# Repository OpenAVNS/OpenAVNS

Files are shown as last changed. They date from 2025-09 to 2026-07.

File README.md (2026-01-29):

# OpenAVNS

## Purpose
To develop an open-source, open-architecture auricular vagus nerve stimulator under a distributed development model.
 
Auricular vagus nerve stimulation (aVNS) is a method of neuromodulation that uses electrical pulses applied to nerves near the ear to create a vagus nerve response. This response can lead to reduced sympathetic (fight or flight) and increased parasympathetic (relaxation / everything ok) tone. Adjusting vagal tone using aVNS has been explored by clinical researchers for a number of potential therapeutic applications, including for depression [1], opioid withdraws [2], chronic pain [3], and gastrointestinal issues [4]. In addition, aVNS has been explored in wellness for applications such as stress reduction [5]. We believe an open-source, open-architecture aVNS system would be helpful for users, students, medical researchers, and community members around the world to explore aVNS and to learn more about developing neuromodulation devices under an open source model.
 
1. [Tan, Chaoren et. al. 2023](https://pubmed.ncbi.nlm.nih.gov/37230264/)  
2. [Tirado, Carlos F. et. al. 2022](https://pmc.ncbi.nlm.nih.gov/articles/PMC9385243/)  
3. [Duff, Irina T. et. al. 2024](https://pmc.ncbi.nlm.nih.gov/articles/PMC11543973/)  
4. [Veldman, Fleur et. al. 2025](https://pmc.ncbi.nlm.nih.gov/articles/PMC11769675/)  
5. [Sanches-Perez, Jesus et. al. 2023](https://pmc.ncbi.nlm.nih.gov/articles/PMC10512834/)  

## Principles of OpenAVNS
* _Openness_ – all source files, including code, PCB source files, CAD, and any documentation, available under permissive license
* _Accessibility_ – device developed using freely available tools (KiCad for PCBs, FreeCAD for enclosure, etc.); enclosure able to be 3D printed on home printer; PCBs use only common, off the shelf components and able to be taped out and assembled by a low-cost manufacturer; clear instructions are developed for building, flashing, and testing a device; low-cost, replaceable, commercially available electrodes are used to apply stimulation; apps should be developed on a platform that allows iOS and Android releases simultaneously
* _Wearability_ – device should be as small and unobtrusive as possible while maintaining openness and accessibility. Ideally, all electronics would fit behind the ear (similar to a behind-ear hearing aid or cochlear implant electronics) and can be comfortably worn for at least 30 minutes at a time
* _Effectiveness_ – the device should be capable of outputting stimulation with the same parameters as those used in clinical trials for at least 30 minutes. We note that OpenAVNS cannot be considered to be “effective” for any indication until it has been tested in a clinical trial.
* _Safety_ – the device’s electronics, firmware, software, and mechanical design should all be constructed with user safety in mind, and should be built to the standards of a medical device. We note that until OpenAVNS has been tested and cleared by a regulatory body for human use it cannot be considered “safe”; any use of the source files and documentation in the project must be done for educational purposes only and is done entirely at the user’s own risk. PLEASE DO NOT HURT YOURSELF!
 
## Proposed user needs and design inputs
| User Need | Design Input |
|---|---|
| The device shall apply neuromodulation to the auricular vagus branches at the tragus and cymba concha | Device shall provide two independent biphasic current-controlled stimulation outputs |
| The user shall easily activate, modify, and deactivate stimulation on the device | App shall allow adjustment of stimulation parameters (frequency, pulse width, amplitude) within specified ranges. <br><br> App shall allow initiating and stopping stimulation <br><br> Physical button on device to deactivate stimulation if needed <br><br> App shall be intuitive and easy to use |
| The user shall comfortably wear the device | Weight less than 40g <br><br> Device fits behind ear <br><br> Remains securely in place for 30 minutes of typical non-athletic activity without discomfort |
| The user shall apply neuromodulation typical of clinical studies reported in literature | Adjustable outputs between 1-50Hz, 100-500us pulse width, 0-2mA amplitude <br><br> Capable of outputting at maximum settings on one channel for a minimum of 30min |
| The device is open and accessible to a large range of users in different situations | Rechargeable by USB-C <br><br> Uses commercial off the shelf replaceable electrodes <br><br> App available on iOS and Android platforms |
| The device is safe to use | Device hardware prevents DC charge or amplitudes outside of the operating parameters from presenting at the electrode sites <br><br> Physical button on device to stop stimulation <br><br> Impedance measurement on output used to stop stimulation if electrodes are disconnected (short or open circuit) <br><br> Stimulation stops if wireless connection to app is interrupted <br><br> Firmware automatically stops stimulation after 30min regardless of other factors |

## Project Goals / Timeline
_2025_
* _August:_ set up project structure, onboard contributors, assign tasks, generate block diagrams of system
* _September:_ design and tape out first version of PCB, develop test firmware, generate proof of concept drawings / mock-ups for enclosure and user interface
* _October:_ test and document initial PCB and firmware for power draw, output integrity, and safety, develop initial app prototype, combine board needs and enclosure drawings to create CAD model
* _November:_ tape out second version of PCB designed for enclosure, conduct fit test, create alpha version of iOS and Android app
* _December:_ first system tests of prototype device (HW + FW + Enclosure + App)

## Contributors
Last updated 10/31/2025
* [Alex Baldwin](https://www.linkedin.com/in/alexbbaldwin/) - Founder, PCB schematics and layout
* [Amanda Cheung](https://www.linkedin.com/in/amandacheung8/) - Enclosure CAD
* [Maro Michailidou](https://www.linkedin.com/in/maro-michailidou/) - PCB Layout Review

## Disclaimer
The contents of this document, the OpenAVNS repository on GitHub, and any other documents or communication released by the OpenAVNS project (the “Materials”) are subject to revision. No representation or warranty, express or implied, is provided in relation to the accuracy, correctness, completeness, or reliability of the information, opinions, or conclusions expressed in this repository.

The Materials are experimental in nature and should be used with prudence and appropriate caution. Any use is voluntary and at your own risk.

The Materials are made available “as is” by the contributors to this repository (collectively, “Providers”). Providers expressly disclaim all warranties, express or implied, arising in connection with the Materials, or arising out of a course of performance, dealing, or trade usage, including, without limitation, any warranties of title, noninfringement, merchantability, or fitness for a particular purpose.

Any user of the Materials agrees to forever indemnify, defend, and hold harmless Providers from and against, and to waive any and all claims against Providers for any and all claims, suits, demands, liability, loss or damage whatsoever, including attorneys' fees, whether direct or consequential, on account of any loss, injury, death or damage to any person or (including without limitation all agents and employees of Providers and all property owned by, leased to or used by either Providers) or on account of any loss or damages to business or reputations or privacy of any persons, arising in whole or in part in any way from use of the Materials or in any way connected therewith or in any way related thereto.

The Materials, any related materials, and all intellectual property therein, are owned by Providers.

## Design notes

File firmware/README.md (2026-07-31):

# OpenAVNS Bring-Up Shell

Interactive shell firmware for board bring-up and testing of the OpenAVNS nRF52840 PCBA. Runs on Zephyr RTOS (via the nRF Connect SDK) and provides a command-line interface over **J-Link RTT** or **USB-C serial** for toggling GPIOs, scanning I2C buses, driving the stim outputs, and testing the BLE antenna — no code changes needed to test the board.

## Prerequisites

- [nRF Connect SDK (NCS) toolchain](https://developer.nordicsemi.com/nRF_Connect_SDK/doc/latest/nrf/installation.html) — provides `west`, the Zephyr SDK (`arm-zephyr-eabi-gcc`), and CMake/Ninja
- J-Link Software Pack installed (`JLinkExe`, `JLinkRTTClient`) — needed for SWD flashing and the RTT shell backend
- A J-Link probe (e.g. J-Link EDU Mini) wired to the board's SWD header (SWDIO, SWDCLK, GND, VTref)

## Getting the SDK

This firmware is a standalone Zephyr application — the nRF Connect SDK itself (several GB) is **not** vendored in this repo. `firmware/west.yml` is a [west manifest](https://developer.nordicsemi.com/nRF_Connect_SDK/doc/latest/zephyr/guides/west/index.html) that lets you bootstrap a matching SDK workspace from scratch:

```bash
west init -m https://github.com/<org>/OpenAVNS --mf firmware/west.yml --mr main workspace
cd workspace
west update
```

This pulls the exact NCS/Zephyr/nrfxlib revisions this firmware was last built and tested against (pinned in `west.yml`). It's a development snapshot rather than a numbered NCS release — see the comments at the top of `west.yml` if you'd rather move to a stable release tag.

After `west update`, the repo itself is checked out at `workspace/openavns/`, so this application lives at `workspace/openavns/firmware`.

**Already have an NCS workspace set up?** You don't need the `west init` step — just copy or symlink this `firmware/` directory in as an application alongside your existing `zephyr`/`nrf` checkout, and build directly (see below).

## Build

```bash
west build -b nrf52840dk/nrf52840 -p always openavns/firmware   # from the workspace root
```

(If you're already inside `firmware/` within a west workspace, `west build -b nrf52840dk/nrf52840 -p always` works too — west walks up to find the workspace root automatically.)

## Flash

Connect your J-Link to the board's SWD header (SWDIO, SWDCLK, GND, VTref), then plug the J-Link into your computer via USB.

```bash
west flash --runner jlink
```

If the flash succeeds, your MCU is alive and soldered correctly.

## Connect to the Shell

Two shell backends run simultaneously and independently — use whichever is convenient.

### Option A: USB-C Serial (simpler)

Plug the board into your computer via USB-C. A serial device will appear:

```bash
ls /dev/tty.usbmodem*
```

Connect with any serial terminal at any baud rate (USB CDC-ACM ignores baud):

```bash
screen /dev/tty.usbmodem1101 115200
```

You should see the shell prompt. Press Enter if it doesn't appear immediately. To exit `screen`: `Ctrl-A` then `K`, then `y`.

### Option B: J-Link RTT

Requires the J-Link connected via SWD. Use two terminals:

**Terminal 1** — start the J-Link GDB server (keeps the RTT connection alive):
```bash
JLinkExe -device NRF52840_XXAA -if SWD -speed 4000 -autoconnect 1
```

**Terminal 2** — connect to the shell:
```bash
JLinkRTTClient
```

Press Enter if the prompt doesn't appear immediately.

> **Note:** JLinkRTTClient does not support paste — all commands must be typed character by character. USB-C serial does not have this limitation.

Both options show:
```
nRF52840 bring-up shell ready
Type 'help' for commands
uart:~$
```

## Shell Commands

### Square-Wave Generator — Frequency Sweep

Use this to characterize how fast your analog circuits can respond. The pin toggles symmetrically (equal high and low times) at the specified half-period.

```
sq start <gpio_dev> <pin> <half_period_us>   # start toggling
sq stop                                       # stop and drive pin LOW
sq status                                     # show current state
```

The `half_period_us` argument is the time spent HIGH (and LOW) in microseconds. The full cycle period is `2 × half_period_us`, so the output frequency is `500000 / half_period_us` Hz.

**Examples:**
```
sq start gpio0 15 1        # P0.15 at ~500 kHz (1 us half-period)
sq start gpio0 15 10       # P0.15 at ~50 kHz  (10 us half-period)
sq start gpio0 15 500      # P0.15 at ~1 kHz   (500 us half-period)
sq start gpio0 15 1000     # P0.15 at ~500 Hz  (1 ms half-period)
sq start gpio0 15 100000   # P0.15 at ~5 Hz    (100 ms half-period)
sq stop
```

To change frequency or pin, just call `sq start` again — it reconfigures on the fly.

**Timing notes:**
- Half-periods **< 1 ms** use a CPU busy-wait loop for ~1 µs accuracy. The shell remains responsive (you can still type `sq stop`) because the shell thread runs at a higher priority.
- Half-periods **≥ 1 ms** yield the CPU between toggles, so the shell stays fully snappy.
- On `sq stop`, the pin is driven LOW immediately.

**Typical workflow (frequency sweep):**
1. Connect an oscilloscope or your analog circuit to the pin.
2. Start at a low frequency and increase until the output degrades: `sq start gpio0 15 1000` → `sq start gpio0 15 100` → `sq start gpio0 15 10` → ...
3. `sq stop` when done.

### Stim — Stimulation Output

Combines DAC voltage control and antiphase GPIO toggling into a single command for mimicking real device operation. Both GPIO pins switch simultaneously in opposite states (one HIGH, one LOW) at the specified frequency.

```
stim start <channel> <voltage_mv> <freq_hz>   # start stimulation
stim stop                                      # stop all channels
```

| Channel | DAC address | Positive pin | Negative pin |
|---|---|---|---|
| 1 | 0x62 | P0.15 | P0.16 |
| 2 | 0x63 | P0.17 | P0.19 |

Voltage is specified in **millivolts** (0–3300). Frequency in **Hz**.

**Examples:**
```
stim start 1 1000 10      # ch1: 1.0V, 10 Hz
stim start 1 2500 100     # ch1: 2.5V, 100 Hz
stim start 2 1650 50      # ch2: 1.65V (mid-rail), 50 Hz
stim stop                 # stop, drive all pins LOW, zero both DACs
```

**Notes:**
- `stim stop` zeros **both** DACs and drives all four pins LOW regardless of which channel was active.
- Calling `stim start` while already running restarts cleanly on the new channel/voltage/frequency.
- Timing uses `k_busy_wait` at all frequencies for ~1 µs accuracy. The shell stays responsive since the stim thread runs at a lower priority and the shell can preempt between toggles.

### General

```
help                    # List all available commands
device list             # List all enabled peripherals
kernel version          # Show Zephyr version
kernel uptime           # Show time since boot
```

### GPIO — Toggle Pins

The nRF52840 has two GPIO ports:
- `gpio0` — Port 0 (pins P0.00–P0.31)
- `gpio1` — Port 1 (pins P1.00–P1.15)

```
gpio conf <device> <pin> <flags>        # Configure pin
gpio set <device> <pin> <0|1>           # Set pin HIGH or LOW
gpio get <device> <pin>                 # Read pin state
gpio toggle <device> <pin>              # Toggle pin
gpio blink <device> <pin>               # Blink pin
gpio devices                            # List all GPIO devices
gpio info [device]                      # Show GPIO info
```

**Configuration flags** for `gpio conf`:
- `i` or `o` — input or output (required)
- `u` or `d` — pull up or pull down (optional, open if omitted)
- `h` or `l` — active high or active low (optional, defaults to active high)
- `0` or `1` — initial logic level (optional, defaults to 0)

Flags are combined into a single string, e.g. `oh1` = output, active high, initial level 1.

**Examples:**
```
gpio conf gpio0 13 o                    # Configure P0.13 as output
gpio set gpio0 13 1                     # P0.13 HIGH
gpio set gpio0 13 0                     # P0.13 LOW
gpio toggle gpio0 13                    # Toggle P0.13
gpio conf gpio0 15 iud                  # P0.15 as input with pull-up, active low
gpio get gpio0 15                       # Read P0.15
gpio conf gpio1 2 oh1                   # P1.02 as output, active high, initial HIGH
```

### I2C — Scan and Send Bytes

The enabled I2C bus is `i2c@40003000` (I2C0).

**Scan for devices:**
```
i2c scan i2c@40003000
```
This prints a table of all responding 7-bit addresses. Use this to verify your DACs and other I2C peripherals are connected and powered.

**Read bytes from a device:**
```
i2c read_byte i2c@40003000 <addr> <reg>
```

**Write bytes to a device (e.g. set a DAC value):**
```
i2c write_byte i2c@40003000 <addr> <reg> <value>
```

All values are in **hex**. Addresses are **7-bit** (not left-shifted).

**Important:** JLinkRTTClient does not support pasting commands. You must type each command character by character. This limitation does not apply when using the USB-C serial shell.

**Examples:**
```
i2c scan i2c@40003000                       # Confirm devices show up
i2c read_byte i2c@40003000 0x60 0x00        # Read register 0x00 from addr 0x60
i2c write_byte i2c@40003000 0x60 0x40 0xFF  # Write 0xFF to register 0x40
```

### BLE — Antenna Testing

Broadcasts a non-connectable BLE advertisement so you can verify the antenna using the **nRF Connect** app (iOS or Android).

```
ble start      # begin advertising as "nRF52840 Bringup"
ble stop       # stop advertising
```

**How to test:**
1. `ble start` in the RTT shell
2. Open nRF Connect → **Scanner** tab
3. Look for `nRF52840 Bringup` in the device list
4. Check RSSI — at ~1m distance, a healthy antenna reads roughly **−50 to −70 dBm**
5. `ble stop` when done

If the device doesn't appear at all, suspect the antenna connection (open circuit). If RSSI is unusually weak (below −80 dBm at close range), suspect an impedance mismatch or poor solder joint on the antenna feed.

> For deeper RF characterization (gain, radiation pattern, return loss), use Nordic's **Direct Test Mode** sample flashed separately with a spectrum analyzer or VNA.

### MCP4725 DAC — Set Output Voltage

The board has two MCP4725 12-bit DACs on I2C0:
- Address `62` (0x62)
- Address `63` (0x63)

The MCP4725 supports a "fast write" where the first byte contains the command/power-down bits and the upper 4 bits of the 12-bit value, and the second byte contains the lower 8 bits. Using `write_byte`, the `<reg>` argument becomes the first byte and `<value>` becomes the second.

**Output voltage formula:** Vout = VDD × (D / 4096)

**Common values (assuming VDD = 3.3V):**

| Target Voltage | D (decimal) | D (hex) | Byte 1 (reg) | Byte 2 (value) | Command |
|---|---|---|---|---|---|
| 0.0V | 0 | 000 | `0` | `0` | `i2c write_byte i2c@40003000 62 0 0` |
| 0.5V | 621 | 26D | `2` | `6D` | `i2c write_byte i2c@40003000 62 2 6D` |
| 1.0V | 1241 | 4D9 | `4` | `D9` | `i2c write_byte i2c@40003000 62 4 D9` |
| 1.65V | 2048 | 800 | `8` | `0` | `i2c write_byte i2c@40003000 62 8 0` |
| 2.5V | 3103 | C1F | `C` | `1F` | `i2c write_byte i2c@40003000 62 C 1F` |
| 3.3V | 4095 | FFF | `F` | `FF` | `i2c write_byte i2c@40003000 62 F FF` |

Replace `62` with `63` for the second DAC.

**How to compute the bytes for any voltage:**
1. D = round(Vtarget / VDD × 4096)
2. Byte 1 (reg) = upper nibble of D (D >> 8)
3. Byte 2 (value) = lower 8 bits of D (D & 0xFF)

### LIS2DH12 IMU — Read Accelerometer

The board has a LIS2DH12 3-axis accelerometer on I2C0 at address `18` (0x18).

**Verify the device is alive:**
```
i2c read_byte i2c@40003000 0x18 0x0F
```
The WHO_AM_I register (0x0F) should return `0x33`.

**Enable the accelerometer:**
```
i2c write_byte i2c@40003000 0x18 0x20 0x57
```
This writes 0x57 to CTRL_REG1 (0x20): 100Hz data rate, normal mode, X/Y/Z axes enabled.

**Read acceleration data:**
```
i2c read_byte i2c@40003000 0x18 0x28       # OUT_X_L
i2c read_byte i2c@40003000 0x18 0x29       # OUT_X_H
i2c read_byte i2c@40003000 0x18 0x2A       # OUT_Y_L
i2c read_byte i2c@40003000 0x18 0x2B       # OUT_Y_H
i2c read_byte i2c@40003000 0x18 0x2C       # OUT_Z_L
i2c read_byte i2c@40003000 0x18 0x2D       # OUT_Z_H
```
Each axis is a signed 16-bit value (little-endian, left-justified). Combine the high and low bytes: `(OUT_H << 8) | OUT_L`, then interpret as a signed int16. At the default ±2g range, 1 mg/digit (in normal mode, 10-bit resolution: 4 mg/LSB).

**Check if new data is ready:**
```
i2c read_byte i2c@40003000 0x18 0x27
```
STATUS_REG (0x27) — bit 3 (ZYXDA) is set when new data is available on all axes.

**Key registers:**

| Register | Address | Description |
|---|---|---|
| WHO_AM_I | 0x0F | Device ID (reads 0x33) |
| CTRL_REG1 | 0x20 | Data rate, power mode, axis enable |
| CTRL_REG4 | 0x23 | Full-scale selection (±2g/4g/8g/16g) |
| STATUS_REG | 0x27 | Data ready flags |
| OUT_X_L/H | 0x28/0x29 | X-axis acceleration |
| OUT_Y_L/H | 0x2A/0x2B | Y-axis acceleration |
| OUT_Z_L/H | 0x2C/0x2D | Z-axis acceleration |

## Pin Mapping

I2C pins are remapped to the custom board layout via `app.overlay`. GPIO commands work with any pin number directly.

| Function | Port | Pin | Node |
|---|---|-----|---|
| I2C0 SDA | P0 | 13 | `i2c@40003000` |
| I2C0 SCL | P0 | 14 | `i2c@40003000` |

To change I2C pins in the future, edit `app.overlay`.

## Troubleshooting

| Problem | Fix |
|---|-----|
| `west flash` fails with "No J-Link found" | Check USB connection, install/update J-Link software |
| `west flash` fails with "Could not connect to target" | Check SWD wiring (SWDIO, SWDCLK, GND, VTref). Verify VTref reads board voltage. If it still fails, try `west -v flash` for verbose output — a misleading "Flashing file: ..." message can appear even when the underlying JLink connection failed. |
| RTTClient shows nothing | Make sure JLinkExe is running in another terminal first. Press Enter a few times. |
| USB-C serial device doesn't appear (`/dev/tty.usbmodem*`) | Check D+/D- continuity from connector to nRF52840. Verify 5.1kΩ pull-downs on CC1 and CC2. Try flipping the cable (USB-C orientation). |
| USB-C serial appears but shell is unresponsive | Press Enter once to wake the shell. The CDC-ACM device enumerates before the shell is fully ready. |
| `i2c scan` shows no devices | Check wiring, pull-up resistors, and power to I2C peripherals. Verify you're using the right pins (P0.13/P0.14 per `app.overlay`). |
| GPIO toggle has no effect | Double-check pin number matches your schematic. Remember Port 1 uses `gpio1`. |
| Commands fail with "wrong parameter count" | JLinkRTTClient does not support paste. Type commands manually character by character. |

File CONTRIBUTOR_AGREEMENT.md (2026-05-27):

# Contributor Agreement

Thank you for your interest in contributing to the OpenAVNS project (the “Project”). This Contributor Agreement (“Agreement”) describes the terms under which you make contributions to the Project. By submitting a contribution, you agree to the following:

### 1. Definitions

“Contribution” means any work of authorship, design, code, documentation, or other material you submit to the Project.

“Project” means the open-source hardware, software, documentation, and related materials maintained in the OpenAVNS GitHub repository and associated project folders.

“Parties” means the Providers, OpenAVNS, and any successors.

### 2. License Grant

You retain the copyright to your Contribution.

You agree to license your Contribution in perpetuity under the same license(s) used by the Project: CC-BY 4.0 International

### 3. Warranties

By submitting a Contribution, you represent that:

You are legally entitled to submit it.

You have the right to license it under the Project’s license(s).

Your Contribution does not knowingly infringe the rights of others.

### 4. Medical Device Disclaimer

You acknowledge that:

The Project is research and development only.

Contributions do not create a certified medical product.

The Parties and Project maintainers are not liable for personal or clinical use of unvalidated prototypes.

### 5. Community Standards

You agree to contribute respectfully. This includes using respectful language, providing feedback in a kind and constructive manner, accepting feedback graciously, and avoiding harassment, insults, discrimination of any kind, or disruption of discussions. In addition, you agree to not dismiss safety concerns or encourage unsafe device usage. 
Maintainers reserve the right to remove members of the community that violate these standards.

### 6. Agreement Provisions
 
This Agreement supersedes and is in lieu of any and all other arrangements between the Providers and OpenAVNS.
 
Any amendment to this Agreement shall be made in writing and signed by the Parties
hereto.
 
If any provision of this Agreement shall be invalid or unenforceable, in whole or in part,
then such provision shall be deemed to be modified or restricted to the extent and in the manner necessary to render the same valid and enforceable.
 
This Agreement shall be construed and interpreted in accordance with the internal laws of the United States of America.
 
All notices required or permitted to be given hereunder shall be in writing and shall be
deemed to have been given when the notice is delivered, and receipt is confirmed.
 
No claim or right arising out of a breach or default under this Agreement shall be
discharged in whole or in part by a waiver of that claim or right unless the waiver is supported by consideration and is in writing and executed by the aggrieved party hereto or their or its duly authorized agent.
 
The Parties hereby agree that they will, at all times, act in good faith and make all
attempts to resolve all differences howsoever arising out of or in connection with this Agreement by discussing internally between themselves. In the event a dispute shall arise between the Parties to this agreement and an amicable solution is unable to be reached, it is hereby agreed that the dispute shall be referred to United States Arbitration & Mediation for arbitration in accordance with United States Arbitration & Mediation Rules of Arbitration. The arbitrator’s decision shall be final and binding and judgment may be entered thereon. The Party requesting arbitration must move to arbitrate in writing no later than 15 days after failure to reach an amicable agreement. The Arbitration Tribunal must be held in Los Angeles, California, and it must be governed by California law. In the event a party fails to proceed with arbitration, unsuccessfully challenges the arbitrator’s award, or fails to comply with arbitrator’s award, the other party is entitled to costs of suit including a reasonable attorney’s fee for having to compel arbitration or defend or enforce the award.
 
This agreement shall be governed by the laws of the United States of America Any
dispute arising between the Parties in respect of this Agreement shall be subject to the exclusive jurisdiction of courts in Los Angeles, California.

### 7. Acceptance

By submitting a Contribution (via pull request, issue, or any other form), you agree to this Agreement.

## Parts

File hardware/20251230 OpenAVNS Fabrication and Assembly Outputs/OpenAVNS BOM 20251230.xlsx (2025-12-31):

Id | Designator | Footprint | Quantity | Value | MFG Part # | LCSC Part #
1 | C44,C34 | C_0805_2012Metric | 2 | 22uF
2 | R68,R21,R34,R41,R45,R59,R64,R58,R39,R35,R43,R42,R67 | R_0402_1005Metric | 13 | 100k
3 | C27,C24,C22,C7,C25,C2,C30,C9,C19 | C_0402_1005Metric | 9 | 100nF
4 | T1 | WE-FLYLT_EP13_5465 | 1 | 1:10, 40uH | Wurth 750315839 | DNP
5 | TP25,TP5,TP28,TP18,TP37,TP9,TP10,TP27,TP34,TP11,TP1,TP20,TP14,TP35,TP4,TP17,TP23,TP33,TP12,TP29,TP13,TP36,TP22,TP3,TP26,TP8,TP32,TP2,TP16,TP15,TP7,TP38,TP39,TP31,TP6,TP19,TP21,TP30 | TestPoint_Pad_D2.0mm | 38 | TestPoint |  | DNP
6 | R2,R20,R16,R33 | C_0805_2012Metric | 4 | 150 Ohm
7 | R27,R28,R6,R7 | C_0805_2012Metric | 4 | 4.4k
8 | C39,C36 | C_0805_2012Metric | 2 | 1uF
9 | D14 | LED_0402_1005Metric | 1 | LED Green
10 | R3,R10,R31,R22,R8,R29,R5,R24 | C_0402_1005Metric | 8 | 100 Ohm
11 | U18, U19, U20, U21 | SOT65P210X110-6N | 4 | TS5A3159DCKR | TS5A3159DCKR | C46388
12 | U12,U9 | TI_SO-PowerPAD-8_ThermalVias | 2 | OPA455 | OPA455 | C2922451
13 | C33,C31 | C_0603_1608Metric | 2 | 0.1uF
14 | C4 | C_0402_1005Metric | 1 | 100pF
15 | C13,C20 | C_0402_1005Metric | 2 | 680pF
16 | Q1,Q5 | SOT-143 | 2 | BCV62 | BCV62 | C139953
17 | L2 | L_1008_2520Metric_Pad1.43x2.20mm_HandSolder | 1 | 4.7uH, 1.2A
18 | Q4,Q8 | SOT-143 | 2 | BCV61 | BCV61 | C426788
19 | C43 | C_0805_2012Metric | 1 | 4.7pF
20 | J3,J8,J9 | PinSocket_2x02_P2.54mm_Vertical | 3 | Conn_02x02_Top_Bottom |  | DNP
21 | C47 | C_0603_1608Metric | 1 | 10pF
22 | C48,C49 | C_0805_2012Metric | 2 | 4.7uF
23 | R30,R4,R9,R23 | C_0402_1005Metric | 4 | 1M
24 | C46,C1 | C_0603_1608Metric | 2 | 1uF
25 | D10,D7,D12,D8 | D_SOD-123 | 4 | MBR0530 | MBR0530 | C77336
26 | R25,R26 | R_0402_1005Metric | 2 | 22 Ohm
27 | Q2,Q6 | SOT-23 | 2 | BC847
28 | U7,U3 | SOT-23-6 | 2 | MCP4725xxx-xCH | MCP4725 | C61423
29 | U5 | Nordic_AQFN-73-1EP_7x7mm_P0.5mm | 1 | nRF52840 | nRF52840 | C190794
30 | R37,R36 | R_0402_1005Metric | 2 | 5.1k
31 | D4,D11,D9,D6 | D_SMA | 4 | SS3200 | SS3200 | C65001
32 | Q7,Q3 | SOT-23 | 2 | BC857 | BC857 | C8581
33 | R19,R32,R1,R15 | C_0805_2012Metric | 4 | 1k
34 | L3 | L_7.3x7.3_H3.5 | 1 | 10uH
35 | J2 | Jack_3.5mm_CUI_SJ-3523-SMT_Horizontal | 1 | AudioPlug3 | SJ-3523 | C4991872
36 | C28,C29,C26,C18 | C_0603_1608Metric | 4 | 10uF
37 | R63 | R_0402_1005Metric | 1 | 330
38 | U14 | Texas_S-PVSON-N10_ThermalVias | 1 | TPS61200DRC | TPS61200DRC | C140320
39 | D3 | D_SOD-882 | 1 | PESD5V0L1UL | PESD5V0L1UL | C3001948
40 | C45,C35,C15,C16 | C_1210_3225Metric | 4 | 22uF, 100V
41 | R38,R44 | R_1206_3216Metric | 2 | 10k
42 | J7 | MOLEX_2171790001 | 1 | Molex 2171790001 | Molex 2171790001 | C3197684
43 | U13 | SSOP-8_2.95x2.8mm_P0.65mm | 1 | 74AUC1G74 | 74AUC1G74 | C2677769
44 | U16 | SOIC127P599X175-9N | 1 | LT8304IS8E_PBF | LT8304IS8E_PBF | C580283
45 | U10 | QFN50P200X150X40-10N | 1 | TLV9062 | TLV9062 | C398355
46 | J1 | PinHeader_2x05_P1.27mm_Vertical_SMD | 1 | Conn_ARM_JTAG_SWD_10 |  | C41376037
47 | R48 | R_0402_1005Metric | 1 | 1.2M
48 | C14,C21 | C_0402_1005Metric | 2 | 12pF
49 | J6 | PinHeader_1x01_P1.00mm_Horizontal | 1 | Conn_01x01_Pin |  | DNP
50 | R13,R12 | R_0402_1005Metric | 2 | 4.7k
51 | L5 | L_0402_1005Metric | 1 | 1.8nH, 5%
52 | C42 | C_0805_2012Metric | 1 | 22uF, 50V
53 | C38,C41 | CP_Radial_D6.3mm_P2.50mm | 2 | 10uF, 100V electrolytic |  | DNP
54 | R57 | R_0603_1608Metric | 1 | 2M
55 | D13 | LED_0402_1005Metric | 1 | LED Yellow
56 | R65 | R_0402_1005Metric | 1 | 1k
57 | C11 | C_0402_1005Metric | 1 | 0.8pF
58 | C32 | C_0805_2012Metric | 1 | 10uF
59 | U17 | SOT-23-5 | 1 | MCP73831-2-OT | MCP73831-2-OT | C14879
60 | C12,C17,C23 | C_1210_3225Metric | 3 | 22uF
61 | U15 | SOT95P280X145-5N | 1 | LT1615ES5_TRPBF | LT1615ES5_TRPBF | C515894
62 | R40,R46 | R_1206_3216Metric | 2 | 619 Ohm
63 | R50,R51 | R_0402_1005Metric | 2 | 220k
64 | L4 | L_0402_1005Metric | 1 | 2.7nH, 5%
65 | J4 | PinHeader_1x02_P2.00mm_Vertical | 1 | Conn_01x02_Pin |  | DNP
66 | J5 | PinHeader_1x03_P2.54mm_Vertical | 1 | Conn_01x03_Pin |  | DNP
67 | C5,C8,C6 | C_0603_1608Metric | 3 | 4.7uF
68 | R47 | R_0402_1005Metric | 1 | 2M
69 | R62 | R_0603_1608Metric | 1 | 130k
70 | Y1 | Crystal_SMD_3225-4Pin_3.2x2.5mm | 1 | 32MHz | X322532MOB4SI | C9009
71 | U11 | LGA-12_2x2mm_P0.5mm | 1 | LIS2DH12 | LIS2DH12 | C110926
72 | L1 | L_0402_1005Metric | 1 | 4.7nH, 5%
73 | C10 | C_0402_1005Metric | 1 | 0.5pF
74 | AT1 | ANTENNA_2450AT43B100E | 1 | 2450AT43B100E | 2450AT43B100E | C2917721
75 | C40,C37 | C_1210_3225Metric | 2 | 22uF, 200V
76 | R14,R17,R18,R11 | R_0603_1608Metric_Pad0.98x0.95mm_HandSolder | 4 | 0 Ohm
77 | C3 | C_0402_1005Metric | 1 | 820pF
78 | SW1 | SW_SPDT_CK_JS102011SAQN | 1 | SW_SPDT | JS102011SAQN | C221660
79 | D1,D2 | D_SMA | 2 | SMAJ54CA | SMAJ54CA | C173507
80 | R61 | R_0805_2012Metric_Pad1.20x1.40mm_HandSolder | 1 | 10k
81 | S1 | SW_SPST_PTS647_Sx38 | 1 | 5-1437565-0 | 5-1437565-0 | C266212
82 | U2 | Texas_S-PX2QFN-14 | 1 | TLV9004xRUCR | TLV9004xRUCR | C2058192
83 | D5 | SOT-23 | 1 | SP0502BAHT | SP0502BAHT | C207261
84 | R66 | R_0402_1005Metric | 1 | 2k
85 | R56 | R_0805_2012Metric_Pad1.20x1.40mm_HandSolder | 1 | 100k

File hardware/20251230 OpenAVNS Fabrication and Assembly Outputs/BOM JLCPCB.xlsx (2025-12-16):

Designation | Designator | Footprint | Quantity | Do Not Place?
22uF | C44,C34 | C_0805 | 2
100k | R68,R21,R34,R41,R45,R59,R64,R58,R39,R35,R43,R42,R67 | R_0402 | 13
100nF | C27,C24,C22,C7,C25,C2,C30,C9,C19 | C_0402 | 9
150 Ohm | R2,R20,R33 | C_0805 | 3
4.4k | R27,R28,R6,R7 | C_0805 | 4
1uF | C39,C36 | C_0805 | 2
LED Green | D14 | LED_0402 | 1
100 Ohm | R3,R10,R31,R22,R8,R5,R24 | C_0402 | 7
TS5A3159AYZPR | U1,U8,U6,U4 | Texas_DSBGA-6_0.9x1.4mm_Layout2x3_P0.5mm | 4
0 Ohm | R52,R54,R49,R53,R55,R60,R14,R17,R18,R11 | R_0603_1608Metric_Pad0.98x0.95mm_HandSolder | 10
OPA455 | U12,U9 | TI_SO-PowerPAD-8_ThermalVias | 2
0.1uF | C33,C31 | C_0603 | 2
100pF | C4 | C_0402 | 1
680pF | C13,C20 | C_0402 | 2
BCV62 | Q1,Q5 | SOT-143 | 2
4.7uH, 1.2A | L2 | L_1008_2520Metric_Pad1.43x2.20mm_HandSolder | 1
BCV61 | Q4,Q8 | SOT-143 | 2
4.7pF | C43 | C_0805 | 1
10pF | C47 | C_0603 | 1
4.7uF | C48,C49 | C_0805 | 2
1M | R30,R4,R9,R23 | C_0402 | 4
1uF | C46,C1 | C_0603 | 2
MBR0530 | D10,D7,D12,D8 | D_SOD-123 | 4
22 Ohm | R25,R26 | R_0402 | 2
BC847 | Q2,Q6 | SOT-23 | 2
MCP4725xxx-xCH | U7,U3 | SOT-23-6 | 2
nRF52840 | U5 | Nordic_AQFN-73-1EP_7x7mm_P0.5mm | 1
5.1k | R37,R36 | R_0402\ | 2
SS3200 | D4,D11,D9,D6 | D_SMA | 4
BC857 | Q7,Q3 | SOT-23 | 2
1k | R19,R32,R1 | C_0805_2012Metric | 3
10uH | L3 | L_7.3x7.3_H3.5 | 1
AudioPlug3 | J2 | Jack_3.5mm_CUI_SJ-3523-SMT_Horizontal | 1
10uF | C28,C29,C26,C18 | C_0603 | 4
330 | R63 | R_0402 | 1
TPS61200DRC | U14 | Texas_S-PVSON-N10_ThermalVias | 1
PESD5V0L1UL | D3 | D_SOD-882 | 1
22uF, 100V | C45,C35,C15,C16 | C_1210 | 4
10k | R38,R44 | R_1206 | 2
74AUC1G74 | U13 | SSOP-8_2.95x2.8mm_P0.65mm | 1
LT8304IS8E_PBF | U16 | SOIC127P599X175-9N | 1
TLV9062 | U10 | QFN50P200X150X40-10N | 1
1.2M | R48 | R_0402 | 1
12pF | C14,C21 | C_0402 | 2
4.7k | R13,R12 | R_0402 | 2
1.8nH, 5% | L5 | L_0402 | 1
22uF, 50V | C42 | C_0805 | 1
2M | R57 | R_0603 | 1
LED Yellow | D13 | LED_0402 | 1
1k | R65 | R_0402 | 1
0.8pF | C11 | C_0402 | 1
10uF | C32 | C_0805 | 1
MCP73831-2-OT | U17 | SOT-23-5 | 1
22uF | C12,C17,C23 | C_1210_3225Metric | 3
LT1615ES5_TRPBF | U15 | SOT95P280X145-5N | 1
619 Ohm | R40,R46 | R_1206 | 2
220k | R50,R51 | R_0402 | 2
2.7nH, 5% | L4 | L_0402 | 1
4.7uF | C5,C8,C6 | C_0603 | 3
2M | R47 | R_0402 | 1
130k | R62 | R_0603 | 1
32MHz - X322532MOB4SI | Y1 | Crystal_SMD_3225-4Pin_3.2x2.5mm | 1
LIS2DH12 | U11 | LGA-12_2x2mm_P0.5mm | 1
R_US | R29 | C_0402 | 1
4.7nH, 5% | L1 | L_0402 | 1
0.5pF | C10 | C_0402 | 1
2450AT43B100E | AT1 | ANTENNA_2450AT43B100E | 1
22uF, 200V | C40,C37 | C_1210 | 2
R_US | R16,R15 | C_0805 | 2
820pF | C3 | C_0402 | 1
SW_SPDT | SW1 | SW_SPDT_CK_JS102011SAQN | 1
SMAJ54CA | D1,D2 | D_SMA | 2
10k | R61 | R_0805_2012Metric_Pad1.20x1.40mm_HandSolder | 1
5-1437565-0 | S1 | SW_SPST_PTS647_Sx38 | 1
TLV9004xRUCR | U2 | Texas_S-PX2QFN-14 | 1
SP0502BAHT | D5 | SOT-23 | 1
2k | R66 | R_0402 | 1
100k | R56 | R_0805 | 1

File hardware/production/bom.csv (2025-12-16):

Designator | Footprint | Quantity | Value | LCSC Part # | DNP
AT1 | ANTENNA_2450AT43B100E | 1 | 2450AT43B100E
C1, C46 | 0603 | 2 | 1uF
C10 | 0402 | 1 | 0.5pF
C11 | 0402 | 1 | 0.8pF
C12, C17, C23 | 1210 | 3 | 22uF
C13, C20 | 0402 | 2 | 680pF
C14, C21 | 0402 | 2 | 12pF
C15, C16, C35, C45 | 1210 | 4 | 22uF, 100V
C18, C26, C28, C29 | 0603 | 4 | 10uF
C19, C2, C22, C24, C25, C27, C30, C7, C9 | 0402 | 9 | 100nF
C3 | 0402 | 1 | 820pF
C31, C33 | 0603 | 2 | 0.1uF
C32 | 0805 | 1 | 10uF
C34, C44 | 0805 | 2 | 22uF
C36, C39 | 0805 | 2 | 1uF
C37, C40 | 1210 | 2 | 22uF, 200V
C38, C41 | CP_Radial_D6.3mm_P2.50mm | 2 | 10uF, 100V electrolytic |  | DNP
C4 | 0402 | 1 | 100pF
C42 | 0805 | 1 | 22uF, 50V
C43 | 0805 | 1 | 4.7pF
C47 | 0603 | 1 | 10pF
C48, C49 | 0805 | 2 | 4.7uF
C5, C6, C8 | 0603 | 3 | 4.7uF
D1, D2 | D_SMA | 2 | SMAJ54CA
D10, D12, D7, D8 | D_SOD-123 | 4 | MBR0530
D11, D4, D6, D9 | D_SMA | 4 | SS3200
D13 | 0402 | 1 | LED Yellow
D14 | 0402 | 1 | LED Green
D3 | D_SOD-882 | 1 | PESD5V0L1UL
D5 | SOT-23 | 1 | SP0502BAHT
J1 | PinHeader_2x05_P1.27mm_Vertical_SMD | 1 | Conn_ARM_JTAG_SWD_10 |  | DNP
J2 | Jack_3.5mm_CUI_SJ-3523-SMT_Horizontal | 1 | AudioPlug3
J3 | USB_C_Receptacle_Amphenol_12401548E4-2A | 1 | USB_C_Receptacle
J4 | PinHeader_1x02_P2.00mm_Vertical | 1 | Conn_01x02_Pin |  | DNP
J5 | PinHeader_1x03_P2.54mm_Vertical | 1 | Conn_01x03_Pin |  | DNP
J6 | PinHeader_1x01_P1.00mm_Horizontal | 1 | Conn_01x01_Pin |  | DNP
L1 | 0402 | 1 | 4.7nH, 5%
L2 | 1008 | 1 | 4.7uH, 1.2A
L3 | L_7.3x7.3_H3.5 | 1 | 10uH
L4 | 0402 | 1 | 2.7nH, 5%
L5 | 0402 | 1 | 1.8nH, 5%
Q1, Q5 | SOT-143 | 2 | BCV62
Q2, Q6 | SOT-23 | 2 | BC847
Q3, Q7 | SOT-23 | 2 | BC857
Q4, Q8 | SOT-143 | 2 | BCV61
R1, R19, R32 | 0805 | 3 | 1k
R10, R22, R24, R3, R31, R5, R8 | 0402 | 7 | 100 Ohm
R11, R14, R17, R18, R49, R52, R53, R54, R55, R60 | 0603 | 10 | 0 Ohm
R12, R13 | 0402 | 2 | 4.7k
R15, R16 | 0805 | 2 | R_US
R2, R20, R33 | 0805 | 3 | 150 Ohm
R21, R34, R35, R39, R41, R42, R43, R45, R58, R59, R64, R67, R68 | 0402 | 13 | 100k
R23, R30, R4, R9 | 0402 | 4 | 1M
R25, R26 | 0402 | 2 | 22 Ohm
R27, R28, R6, R7 | 0805 | 4 | 4.4k
R29 | 0402 | 1 | R_US
R36, R37 | 0402 | 2 | 5.1k
R38, R44 | 1206 | 2 | 10k
R40, R46 | 1206 | 2 | 619 Ohm
R47 | 0402 | 1 | 2M
R48 | 0402 | 1 | 1.2M
R50, R51 | 0402 | 2 | 220k
R56 | 0805 | 1 | 100k
R57 | 0603 | 1 | 2M
R61 | 0805 | 1 | 10k
R62 | 0603 | 1 | 130k
R63 | 0402 | 1 | 330
R65 | 0402 | 1 | 1k
R66 | 0402 | 1 | 2k
S1 | SW_SPST_PTS647_Sx38 | 1 | 5-1437565-0
SW1 | SW_SPDT_CK_JS102011SAQN | 1 | SW_SPDT
T1 | WE-FLYLT_EP13_5465 | 1 | Wurth 750315839 - 1:10, 40uH |  | DNP
TP1, TP10, TP11, TP12, TP13, TP14, TP15, TP16, TP17, TP18, TP19, TP2, TP20, TP21, TP22, TP23, TP24, TP25, TP26, TP27, TP28, TP29, TP3, TP30, TP31, TP32, TP33, TP34, TP35, TP36, TP37, TP38, TP39, TP4, TP5, TP6, TP7, TP8, TP9 | TestPoint_Pad_D2.0mm | 39 | TestPoint |  | DNP
U1, U4, U6, U8 | Texas_DSBGA-6_0.9x1.4mm_Layout2x3_P0.5mm | 4 | TS5A3159AYZPR
U10 | QFN50P200X150X40-10N | 1 | TLV9062
U11 | LGA-12_2x2mm_P0.5mm | 1 | LIS2DH12
U12, U9 | TI_SO-PowerPAD-8_ThermalVias | 2 | OPA455
U13 | SSOP-8_2.95x2.8mm_P0.65mm | 1 | 74AUC1G74
U14 | Texas_S-PVSON-N10_ThermalVias | 1 | TPS61200DRC
U15 | SOT95P280X145-5N | 1 | LT1615ES5_TRPBF | LT1615ES5#PBF
U16 | SOIC127P599X175-9N | 1 | LT8304IS8E_PBF
U17 | SOT-23-5 | 1 | MCP73831-2-OT
U2 | Texas_S-PX2QFN-14 | 1 | TLV9004xRUCR
U3, U7 | SOT-23-6 | 2 | MCP4725xxx-xCH
U5 | Nordic_AQFN-73-1EP_7x7mm_P0.5mm | 1 | nRF52840
Y1 | Crystal_SMD_3225-4Pin_3.2x2.5mm | 1 | 32MHz - X322532MOB4SI

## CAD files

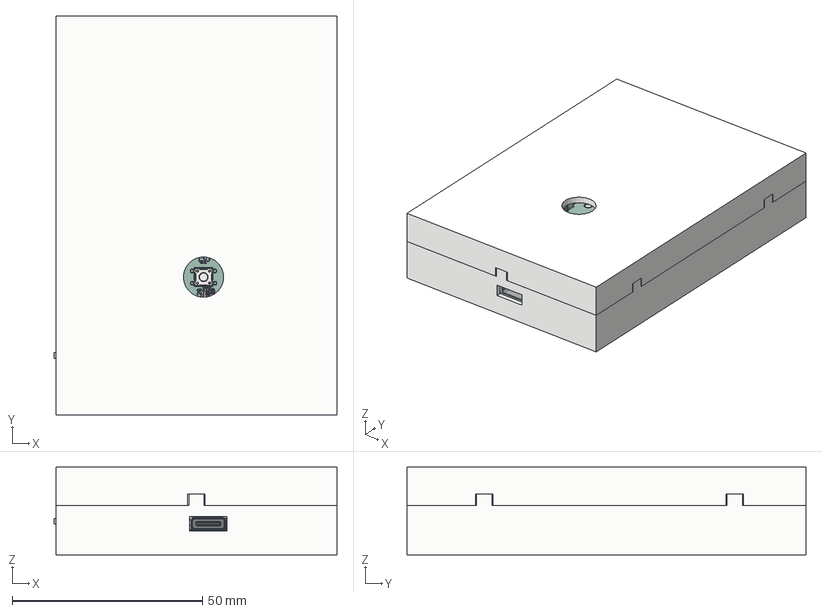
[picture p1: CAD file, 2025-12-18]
Enclosure/PCB housing.step
74.4 x 104.9 x 23.0 mm
C_0805_2012Metric x 21
R_0402_1005Metric x 26
C_0402_1005Metric x 29
Unnamed-Cube
LED_0402_1005Metric x 2
R_0603_1608Metric x 12
HTSOP-8-1EP_3.9x4.9mm_P1.27mm_EP2.4x3.2mm x 2
C_0603_1608Metric x 12
SOT-143 x 4
L_1008_2520Metric
D_SOD-123 x 4
SOT-23 x 5
SOT-23-6 x 2
Nordic_AQFN-73-1EP_7x7mm_P0.5mm
D_SMA x 6
L_Coilcraft_XAL7030-332
Same_Sky_SJ-3523-SMT-TR
Texas_S-PVSON-N10
D_SOD-882
C_1210_3225Metric x 9
R_1206_3216Metric x 4
SSOP-8_2.95x2.8mm_P0.65mm
LT8304IS8E_PBF
TLV9062SIRUGR
PinHeader_2x05_P1.27mm_Vertical_SMD
L_0402_1005Metric x 3
CP_Radial_D6.3mm_P2.50mm x 2
SOT-23-5
PinHeader_1x02_P2.00mm_Vertical
PinHeader_1x03_P2.54mm_Vertical
Crystal_SMD_3225-4Pin_3.2x2.5mm
LGA-12_2x2mm_P0.5mm
2450AT43B100E
JS102011SAQN
R_0805_2012Metric x 2
SW_SPST_PTS647Sx38
USB_C_Receptacle_Amphenol_12401610E4-2A
OpenAVNS KiCad Project_pad
OpenAVNS KiCad Project_silkscreen
OpenAVNS KiCad Project_PCB

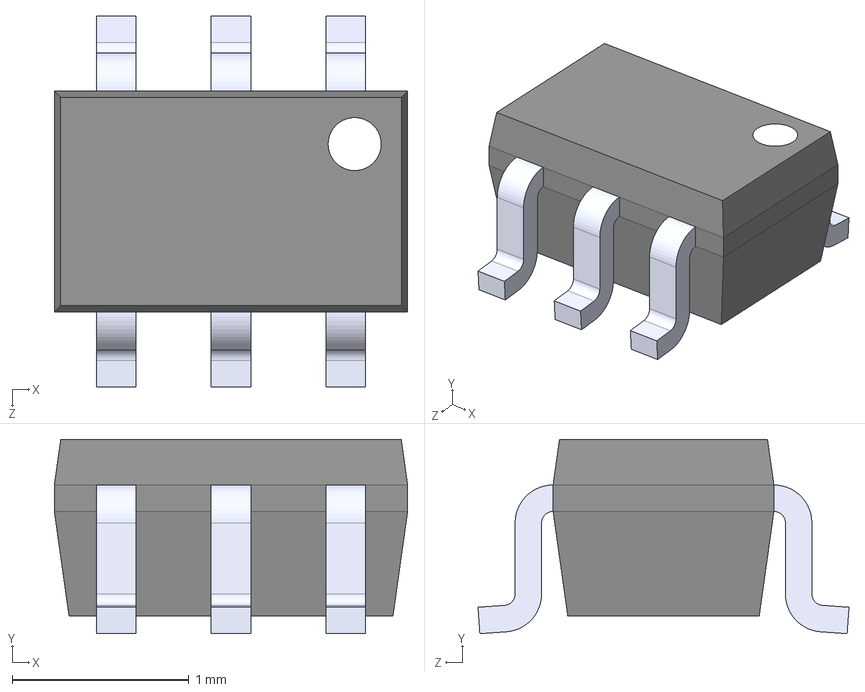
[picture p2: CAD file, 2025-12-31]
hardware/3D Models/TS5A3159DCKR.step
2.00 x 1.10 x 2.10 mm

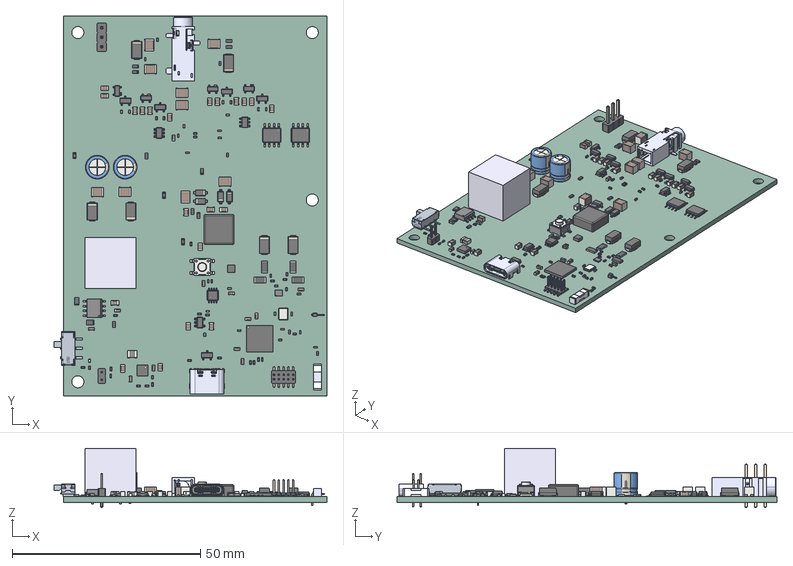
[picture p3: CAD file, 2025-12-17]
hardware/PCB STEP file.step
72.4 x 100.9 x 15.7 mm
C_0805_2012Metric x 21
R_0402_1005Metric x 26
C_0402_1005Metric x 29
Unnamed-Cube
LED_0402_1005Metric x 2
R_0603_1608Metric x 12
HTSOP-8-1EP_3.9x4.9mm_P1.27mm_EP2.4x3.2mm x 2
C_0603_1608Metric x 12
SOT-143 x 4
L_1008_2520Metric
D_SOD-123 x 4
SOT-23 x 5
SOT-23-6 x 2
Nordic_AQFN-73-1EP_7x7mm_P0.5mm
D_SMA x 6
L_Coilcraft_XAL7030-332
Same_Sky_SJ-3523-SMT-TR
Texas_S-PVSON-N10
D_SOD-882
C_1210_3225Metric x 9
R_1206_3216Metric x 4
SSOP-8_2.95x2.8mm_P0.65mm
LT8304IS8E_PBF
TLV9062SIRUGR
PinHeader_2x05_P1.27mm_Vertical_SMD
PinHeader_1x01_P1.00mm_Horizontal
L_0402_1005Metric x 3
CP_Radial_D6.3mm_P2.50mm x 2
SOT-23-5
PinHeader_1x02_P2.00mm_Vertical
PinHeader_1x03_P2.54mm_Vertical
Crystal_SMD_3225-4Pin_3.2x2.5mm
LGA-12_2x2mm_P0.5mm
2450AT43B100E
JS102011SAQN
R_0805_2012Metric x 2
SW_SPST_PTS647Sx38
OpenAVNS KiCad Project_PCB

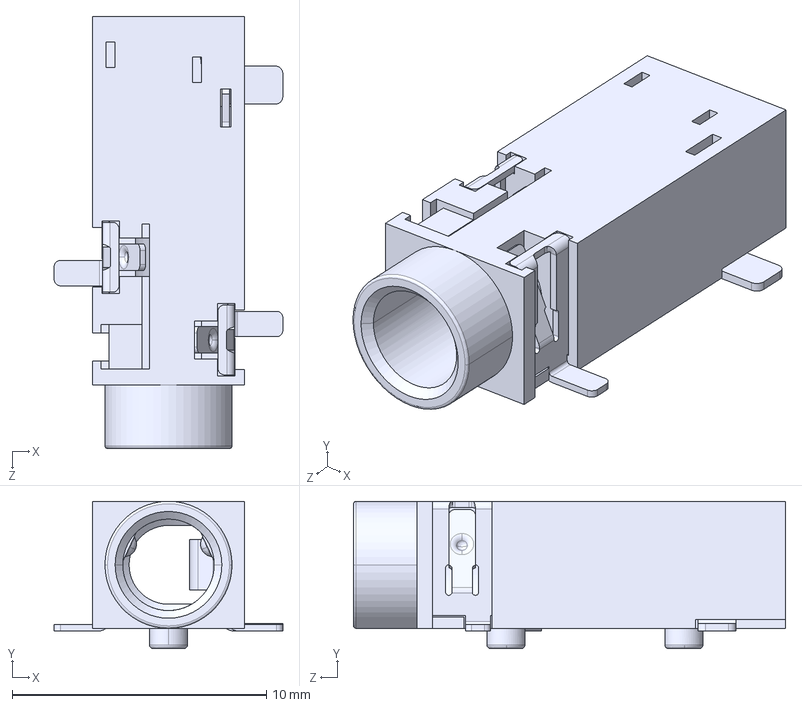
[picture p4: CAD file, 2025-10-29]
hardware/3D Models/Same_Sky_SJ-3523-SMT-TR.step
9.00 x 5.80 x 17.0 mm

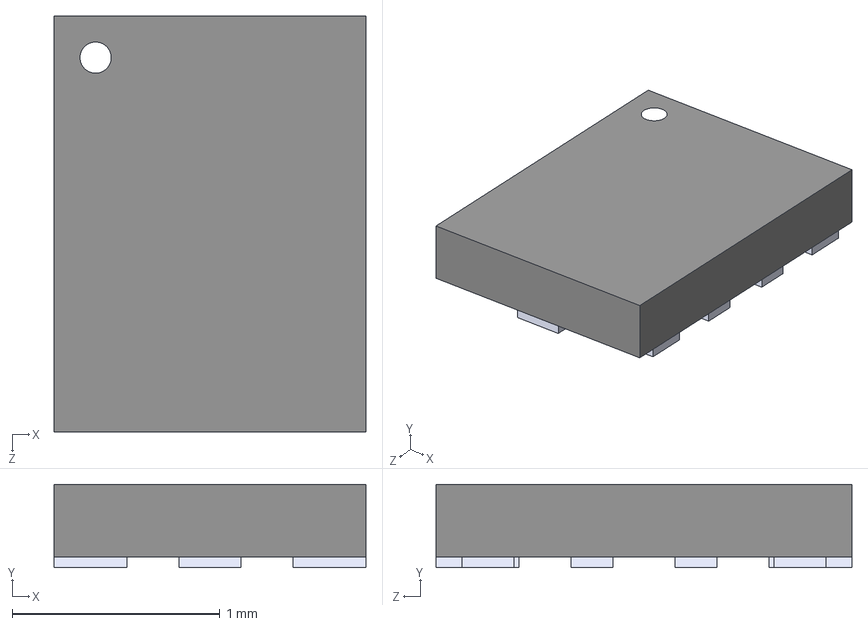
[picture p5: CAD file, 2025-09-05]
hardware/3D Models/TLV9062SIRUGR.step
1.50 x 0.4 x 2.00 mm

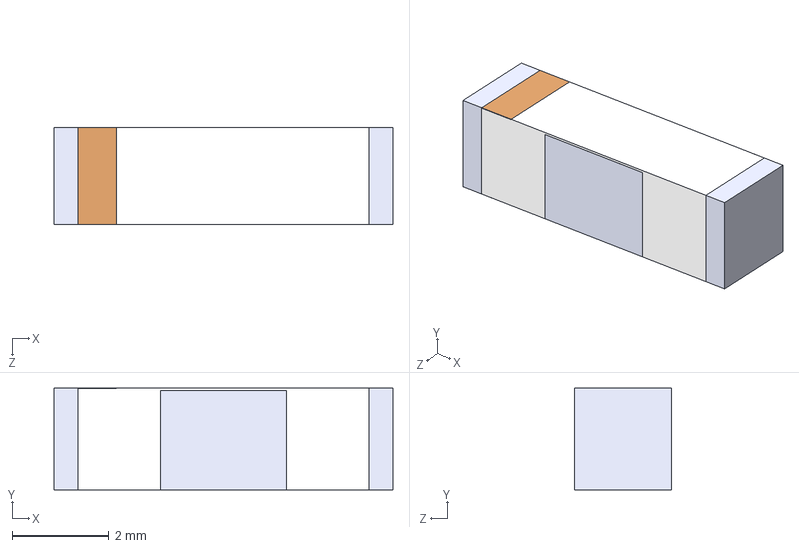
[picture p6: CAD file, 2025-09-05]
hardware/3D Models/2450AT43B100E.step
7.00 x 2.10 x 2.00 mm

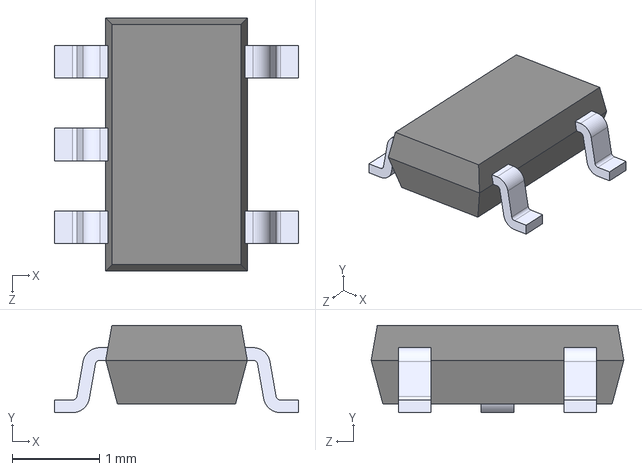
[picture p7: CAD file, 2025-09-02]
hardware/3D Models/LT1615ES5_TRPBF.step
2.80 x 1.00 x 2.90 mm

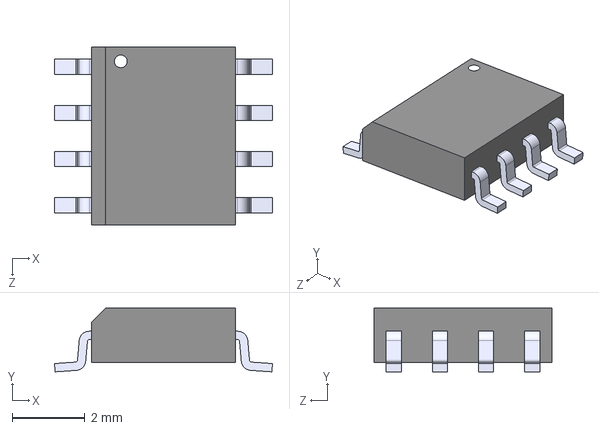
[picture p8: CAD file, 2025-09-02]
hardware/3D Models/LT8304IS8E_PBF.step
5.99 x 1.75 x 4.90 mm

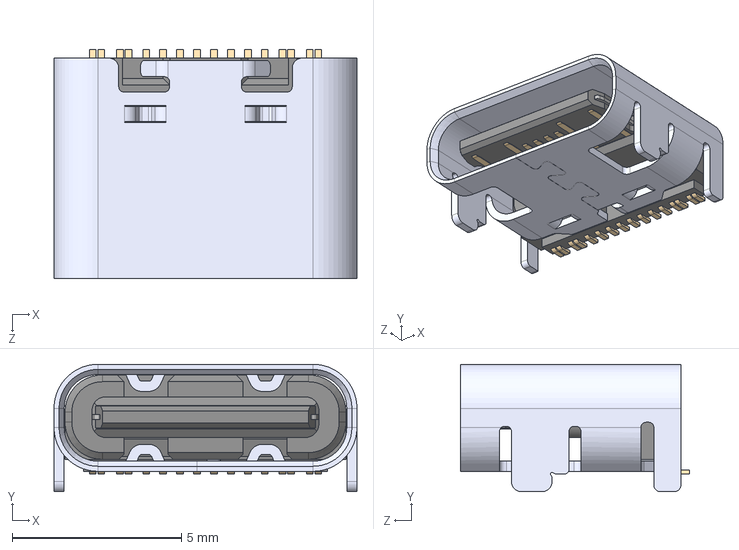
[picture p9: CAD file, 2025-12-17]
hardware/3D Models/2171790001.step
8.94 x 3.76 x 6.75 mm

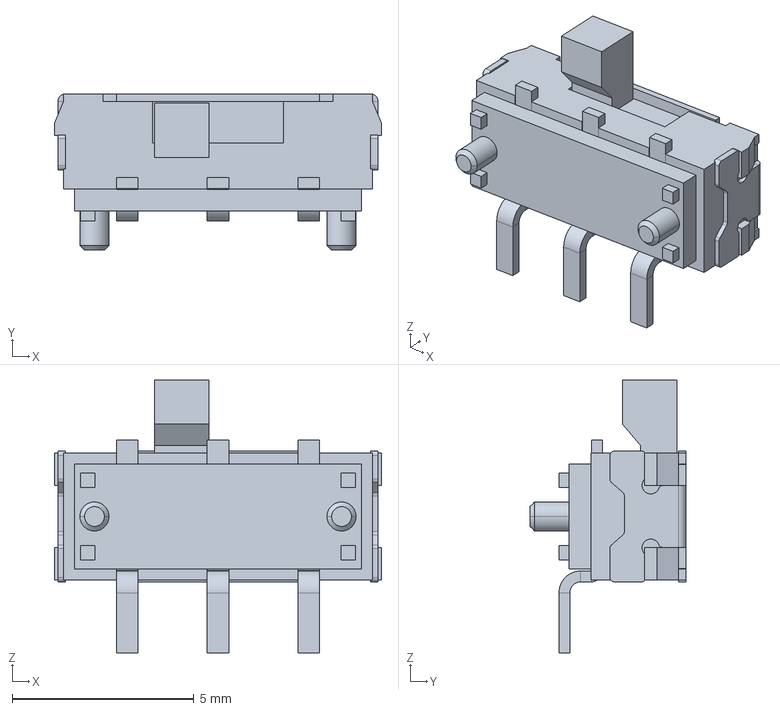
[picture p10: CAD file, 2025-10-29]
hardware/3D Models/JS102011SAQN.STEP
9.00 x 4.30 x 7.50 mm

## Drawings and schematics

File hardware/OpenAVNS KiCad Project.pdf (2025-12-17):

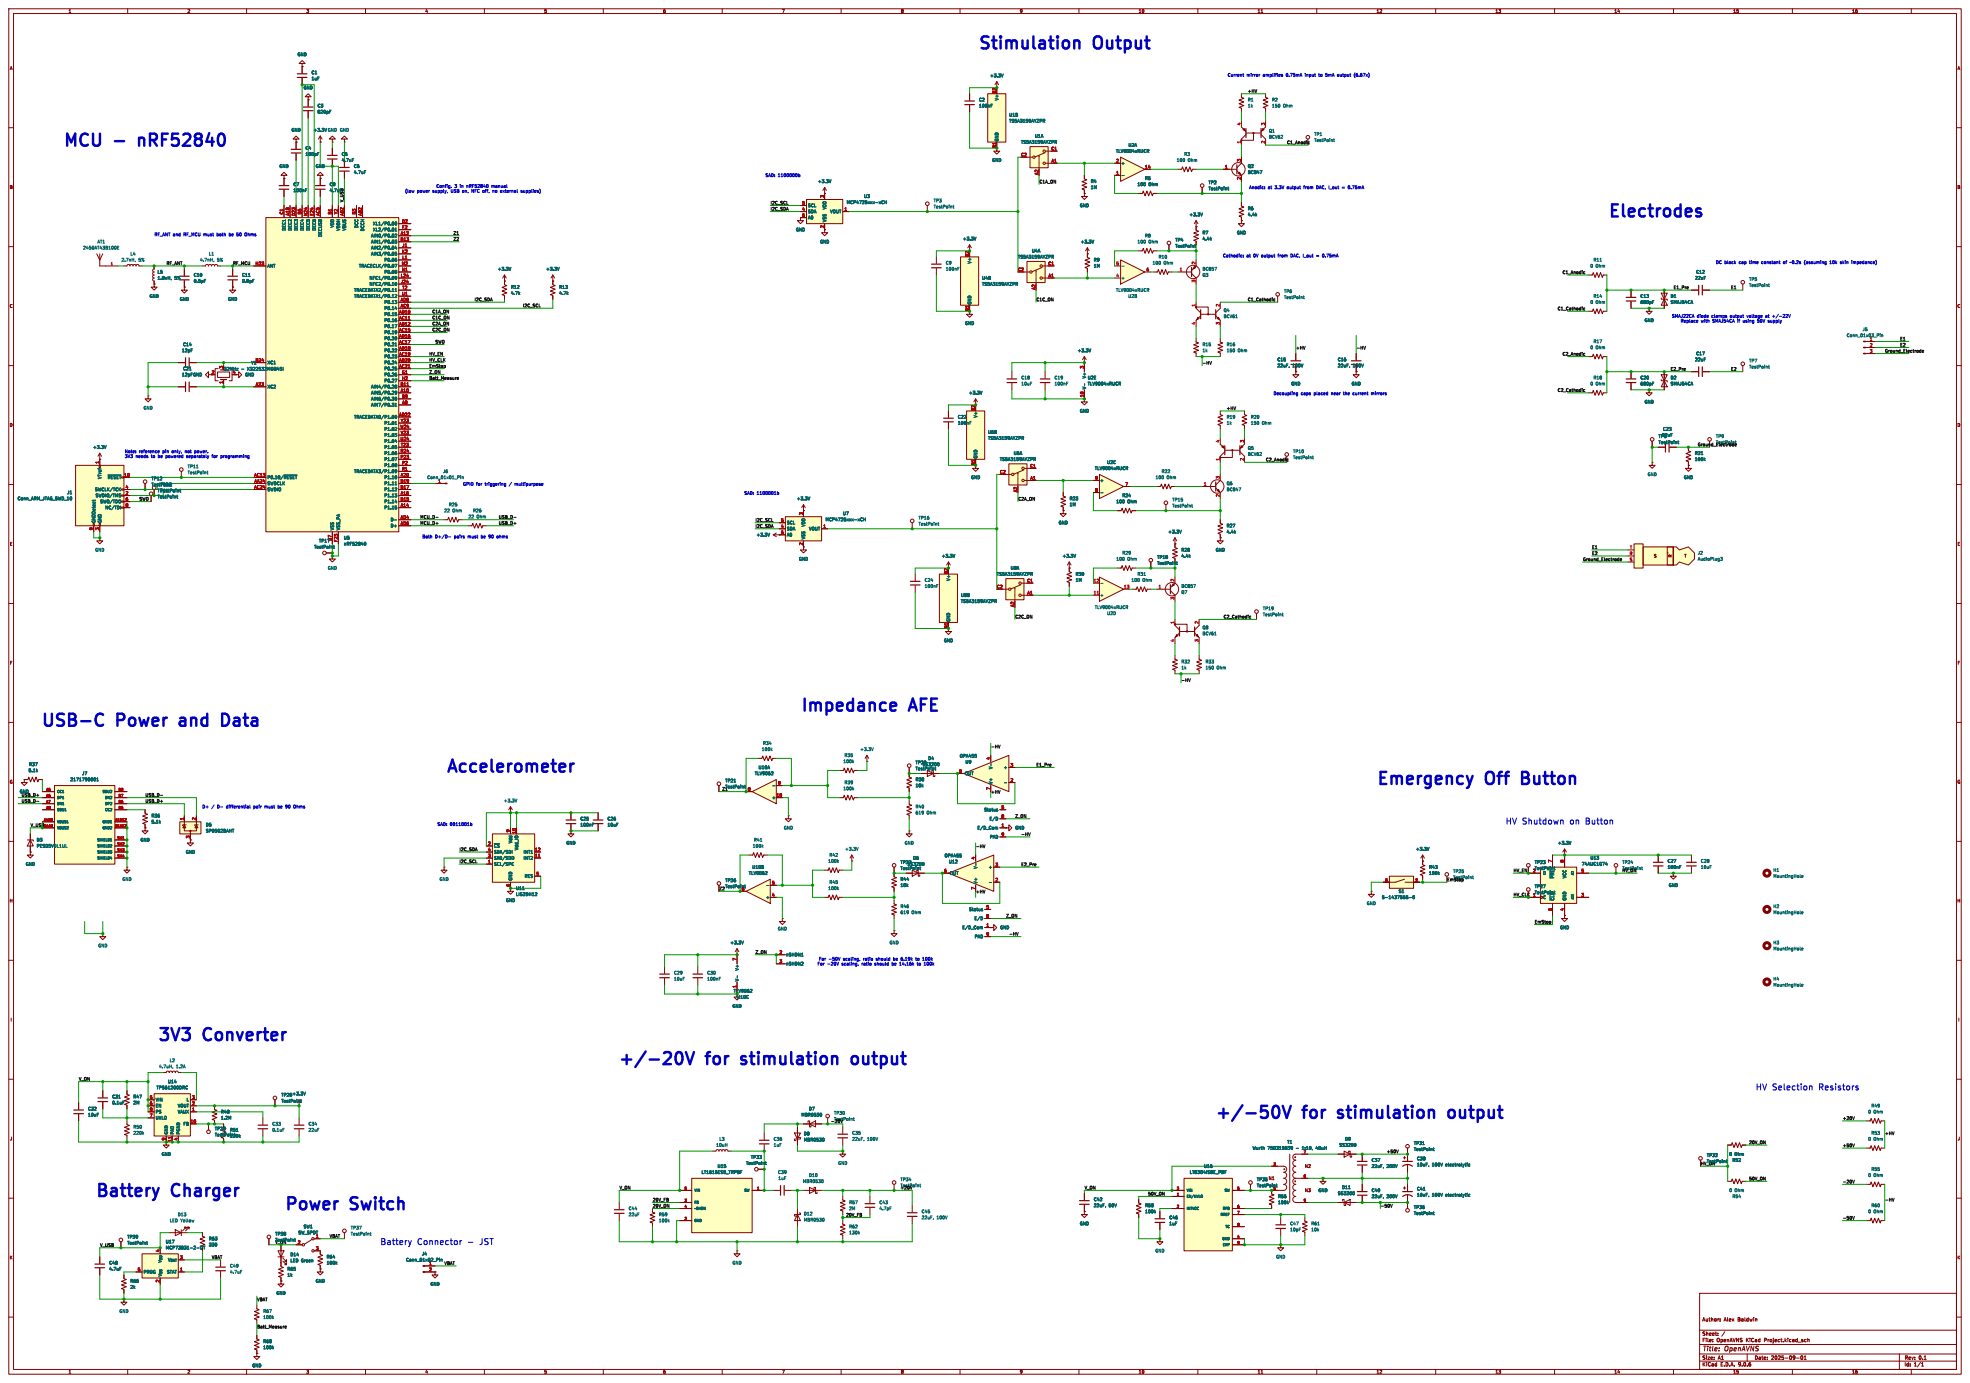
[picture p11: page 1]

3 ~{RESET}10 SWCLK/TCK 4 SWDIO/TMS 2 SWO/TDO 6 NC/TDI 8 TP14 TestPoint TP13 TestPoint TP12 TestPoint GND

3 ~{RESET}10 SWCLK/TCK 4 SWDIO/TMS 2 SWO/TDO 6 NC/TDI 8

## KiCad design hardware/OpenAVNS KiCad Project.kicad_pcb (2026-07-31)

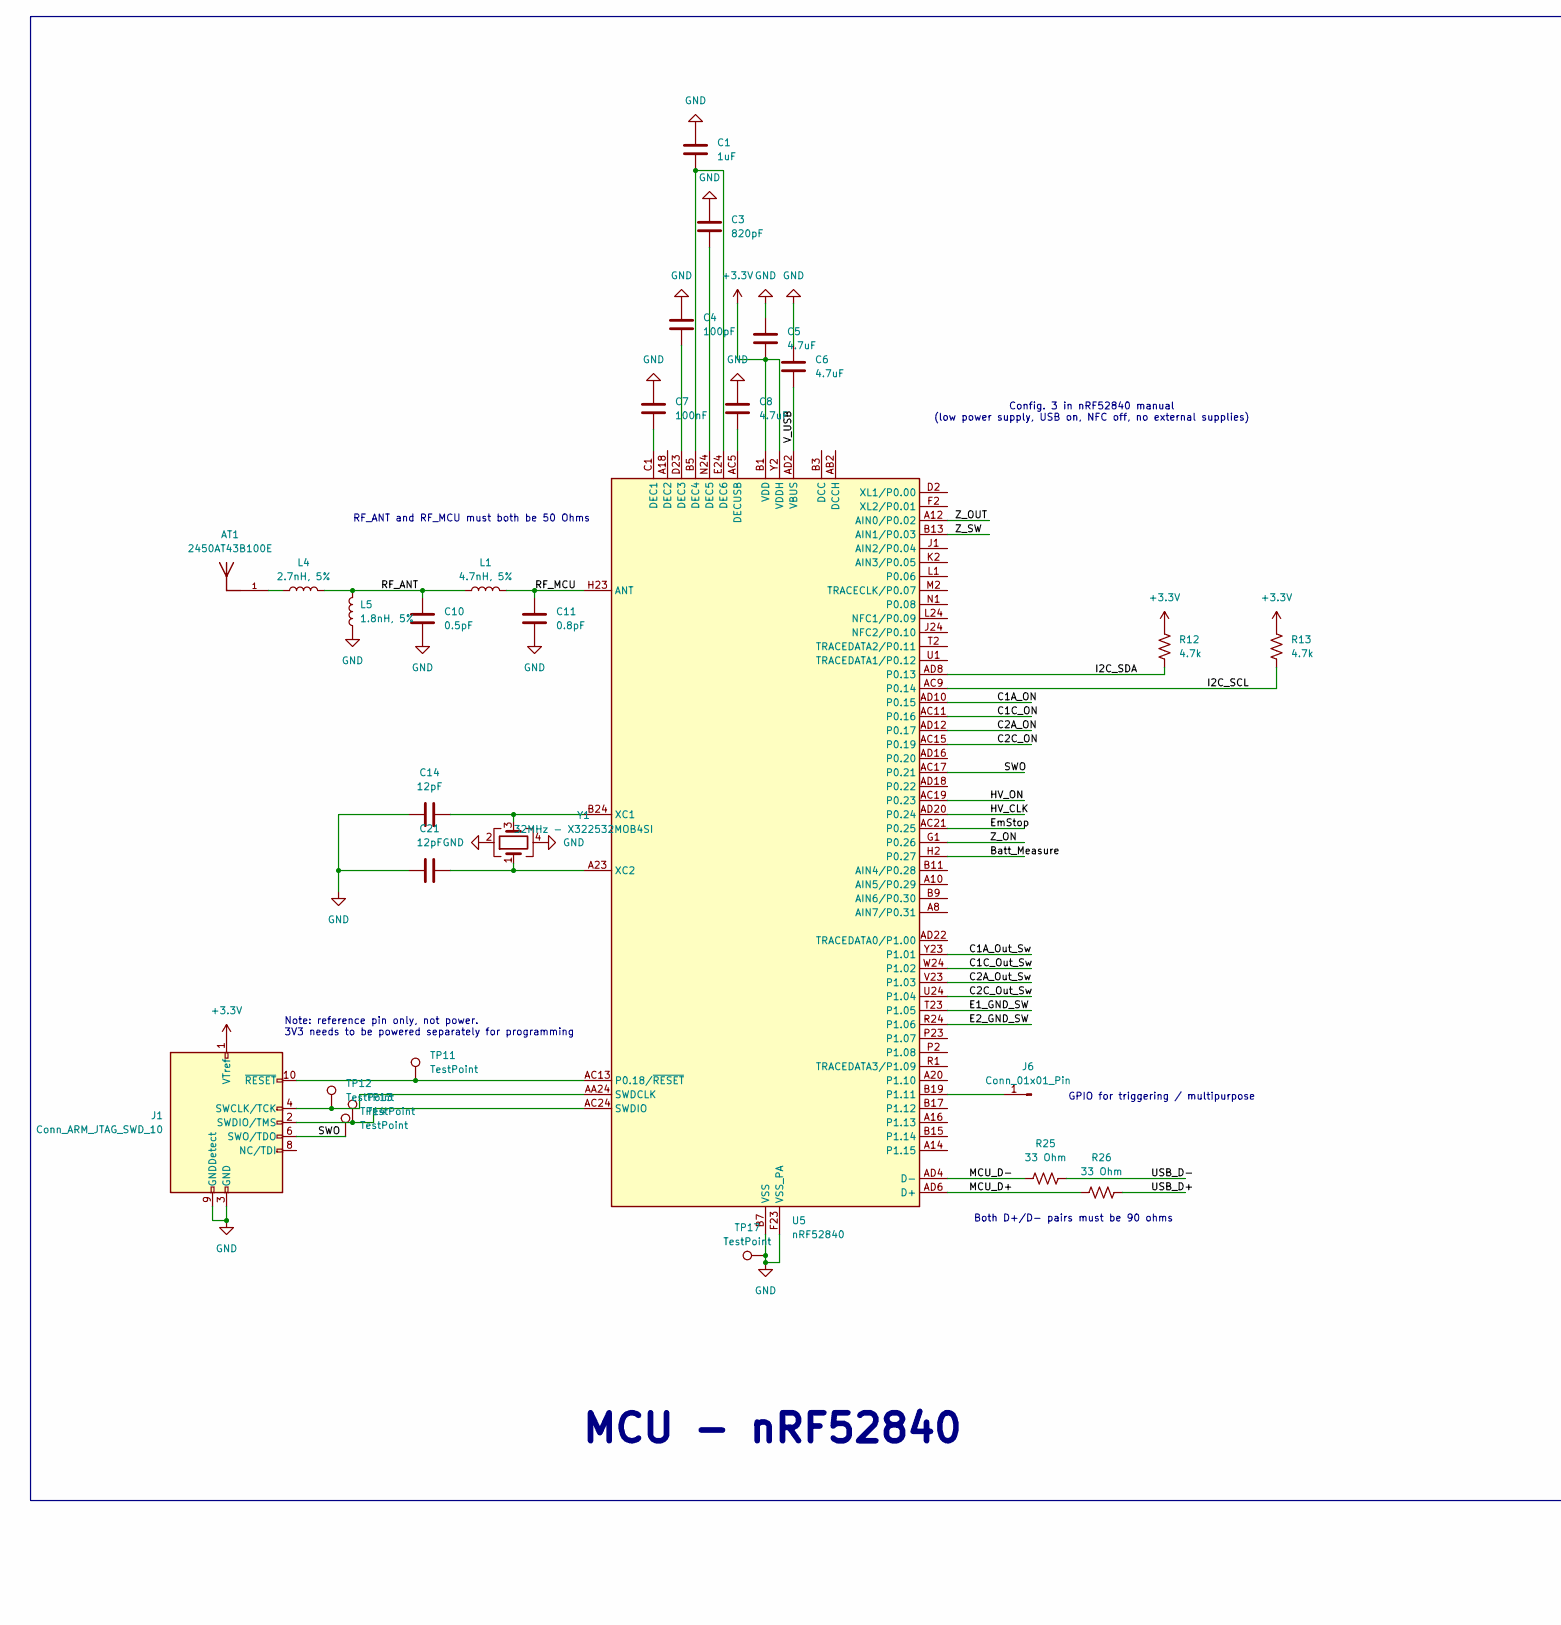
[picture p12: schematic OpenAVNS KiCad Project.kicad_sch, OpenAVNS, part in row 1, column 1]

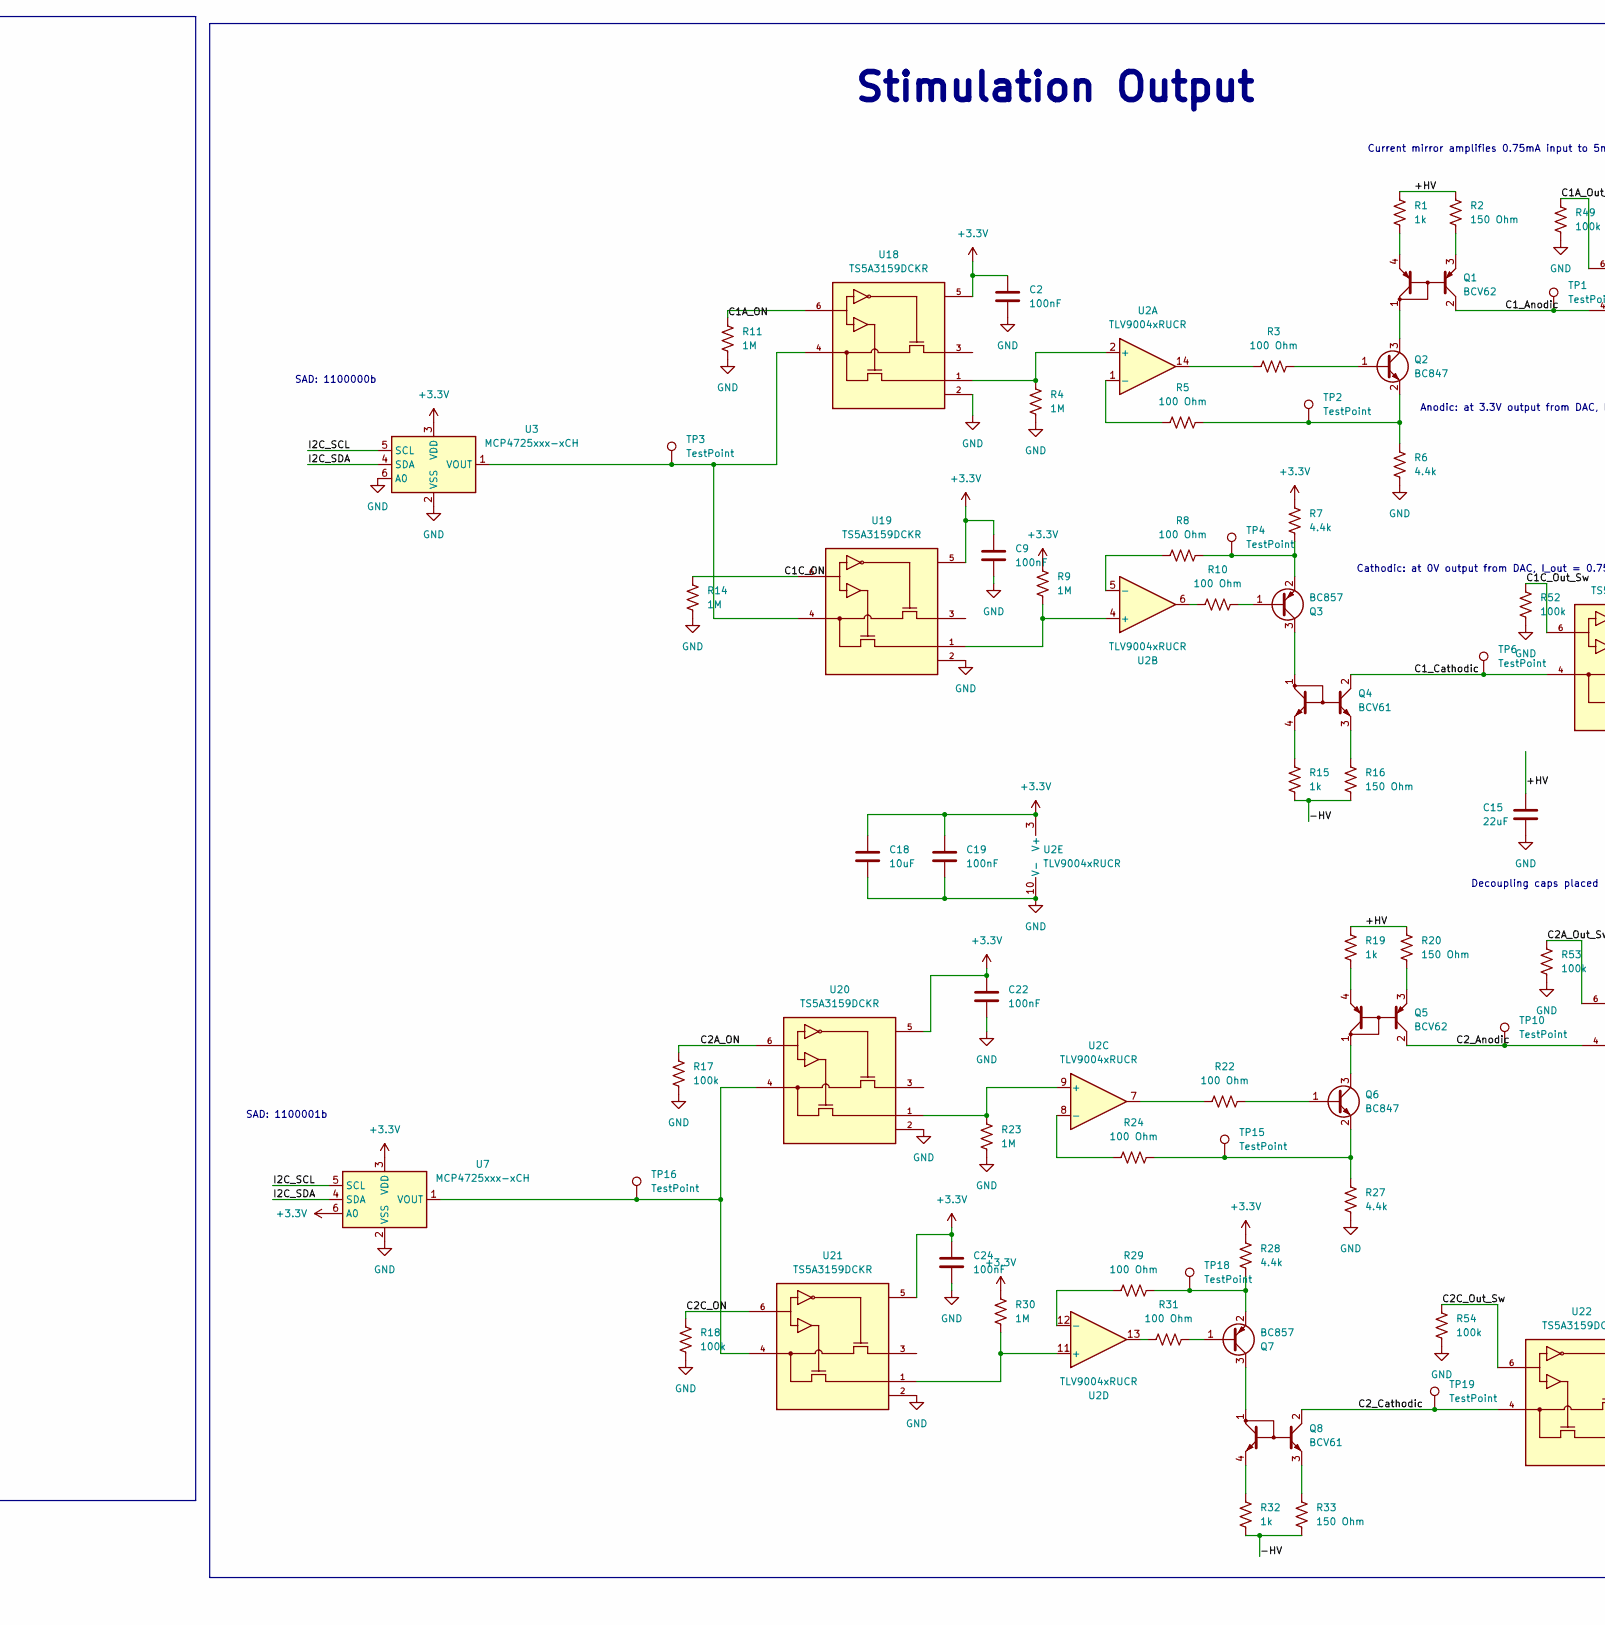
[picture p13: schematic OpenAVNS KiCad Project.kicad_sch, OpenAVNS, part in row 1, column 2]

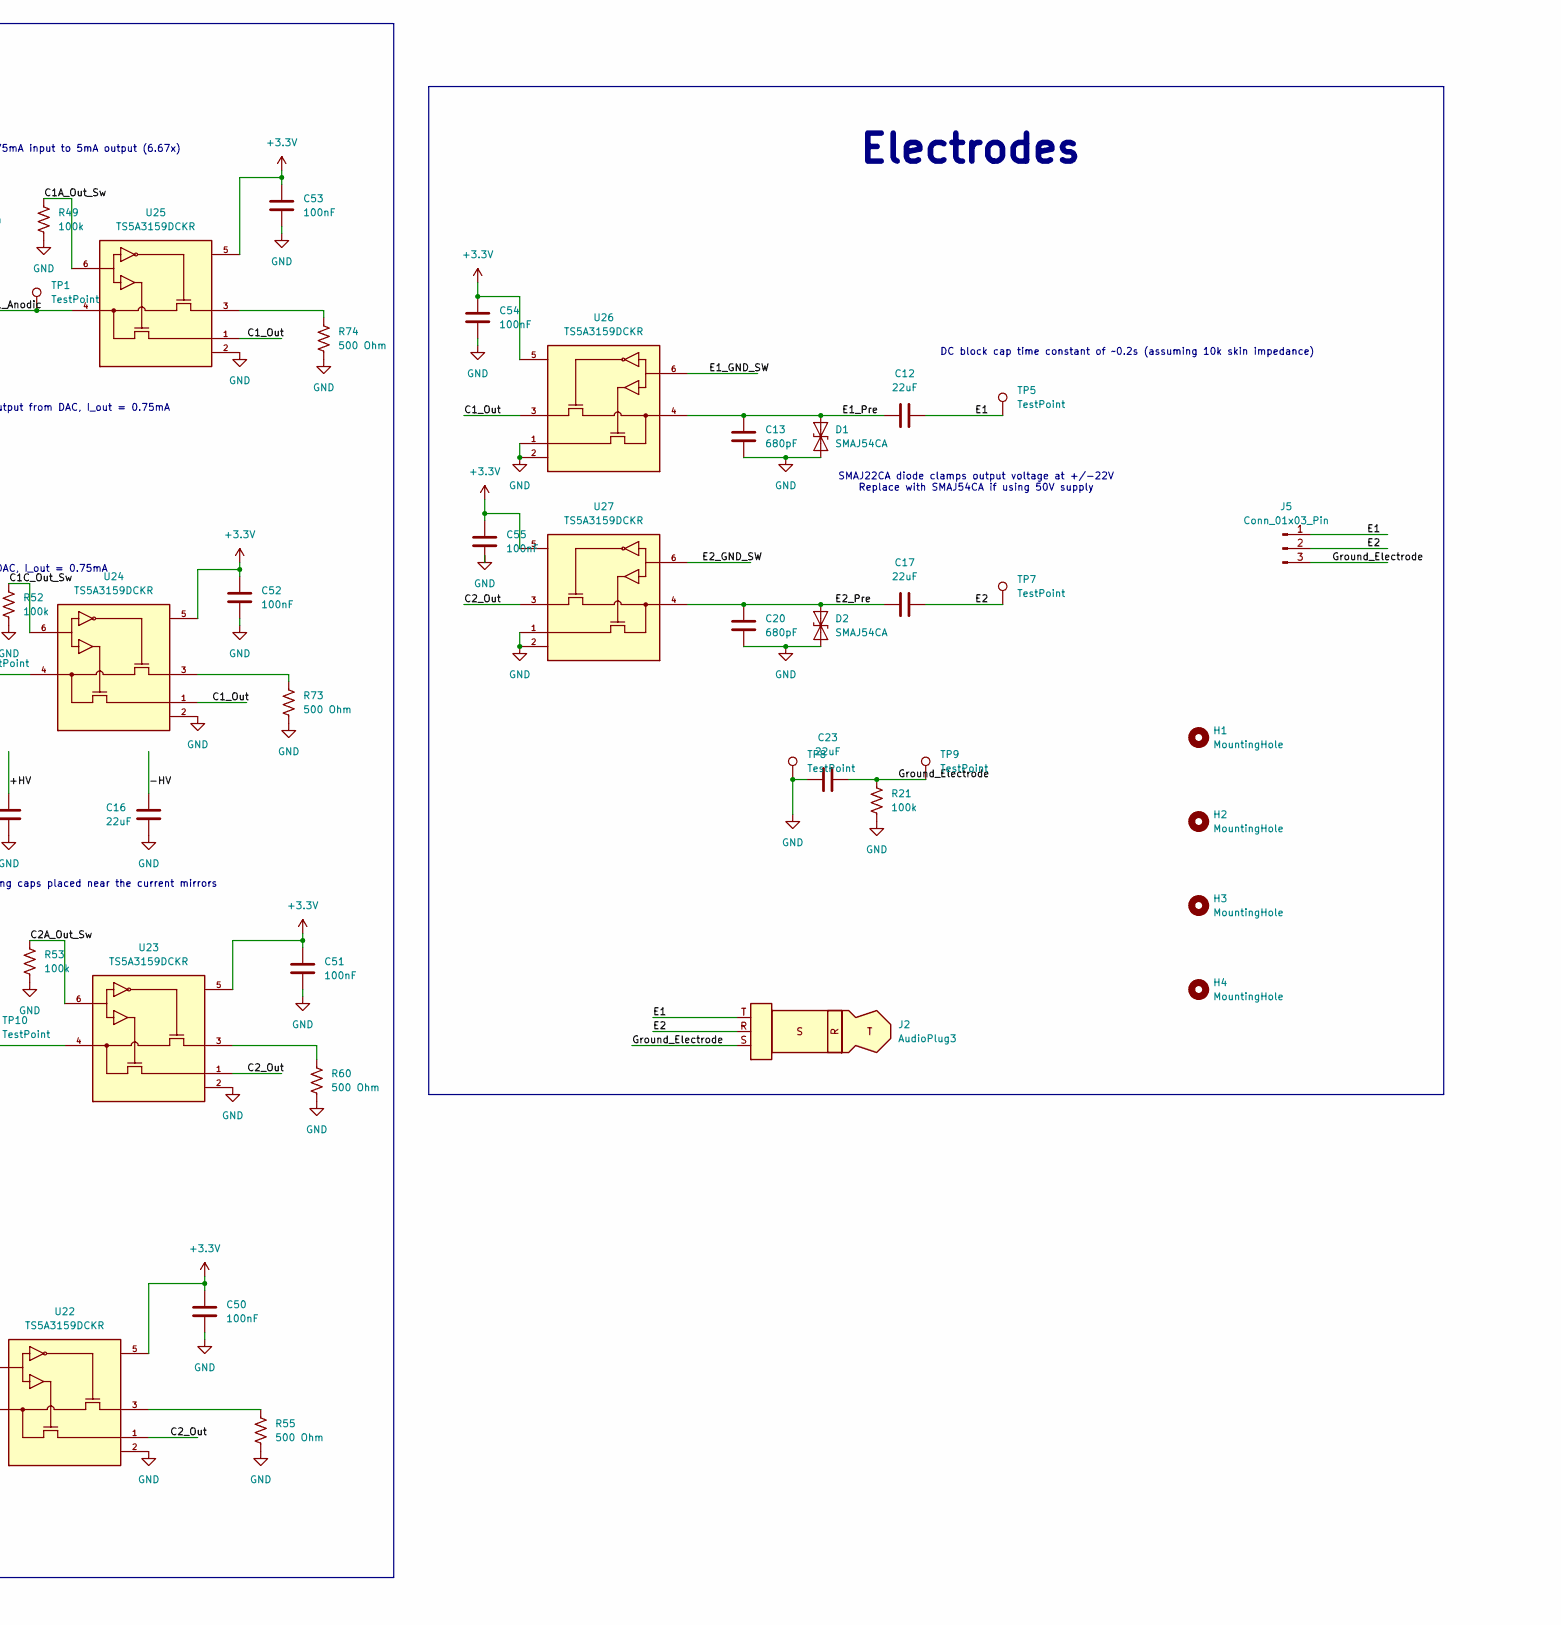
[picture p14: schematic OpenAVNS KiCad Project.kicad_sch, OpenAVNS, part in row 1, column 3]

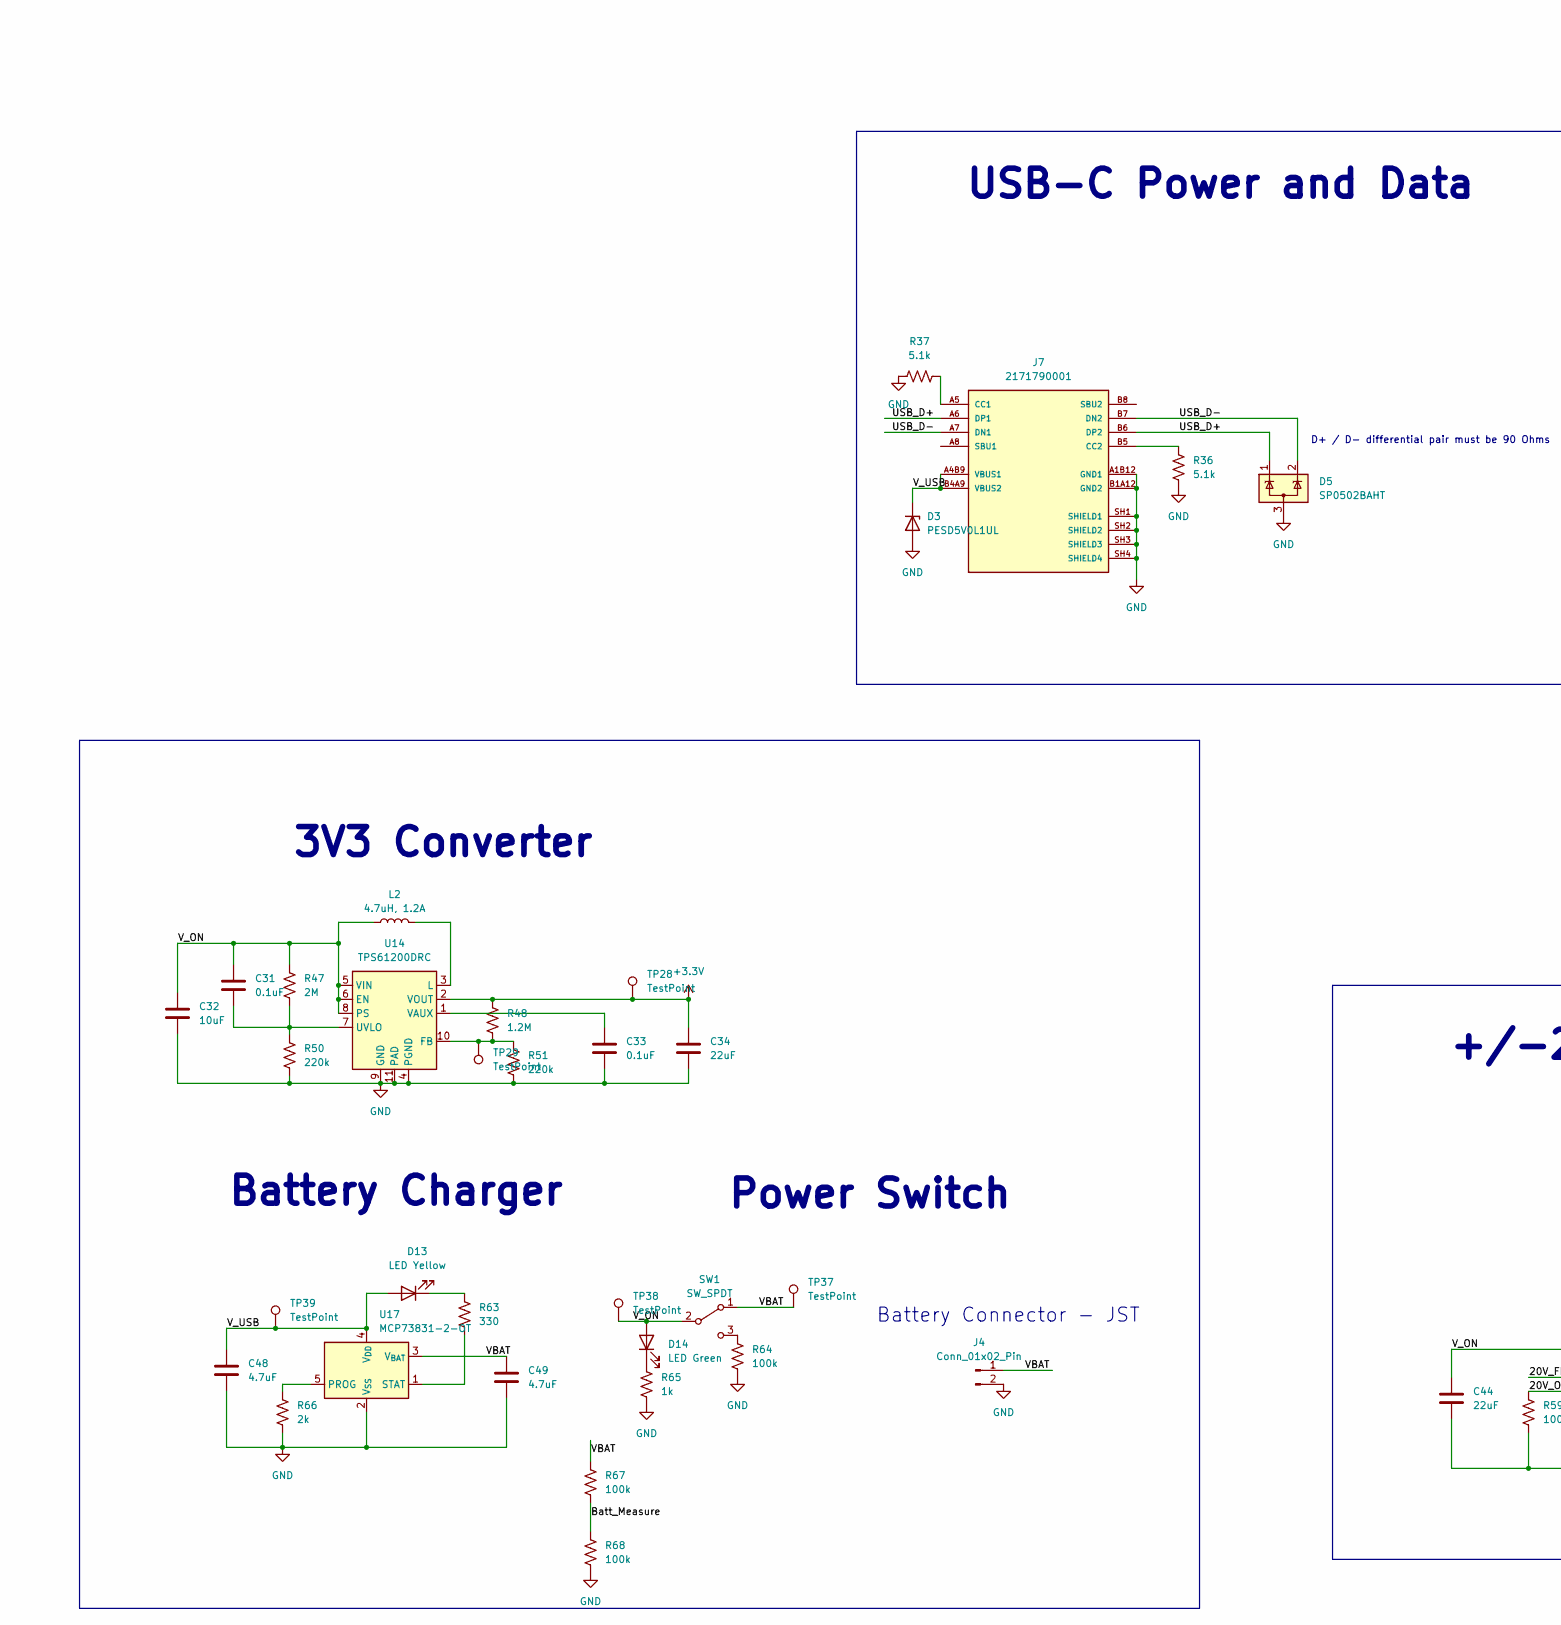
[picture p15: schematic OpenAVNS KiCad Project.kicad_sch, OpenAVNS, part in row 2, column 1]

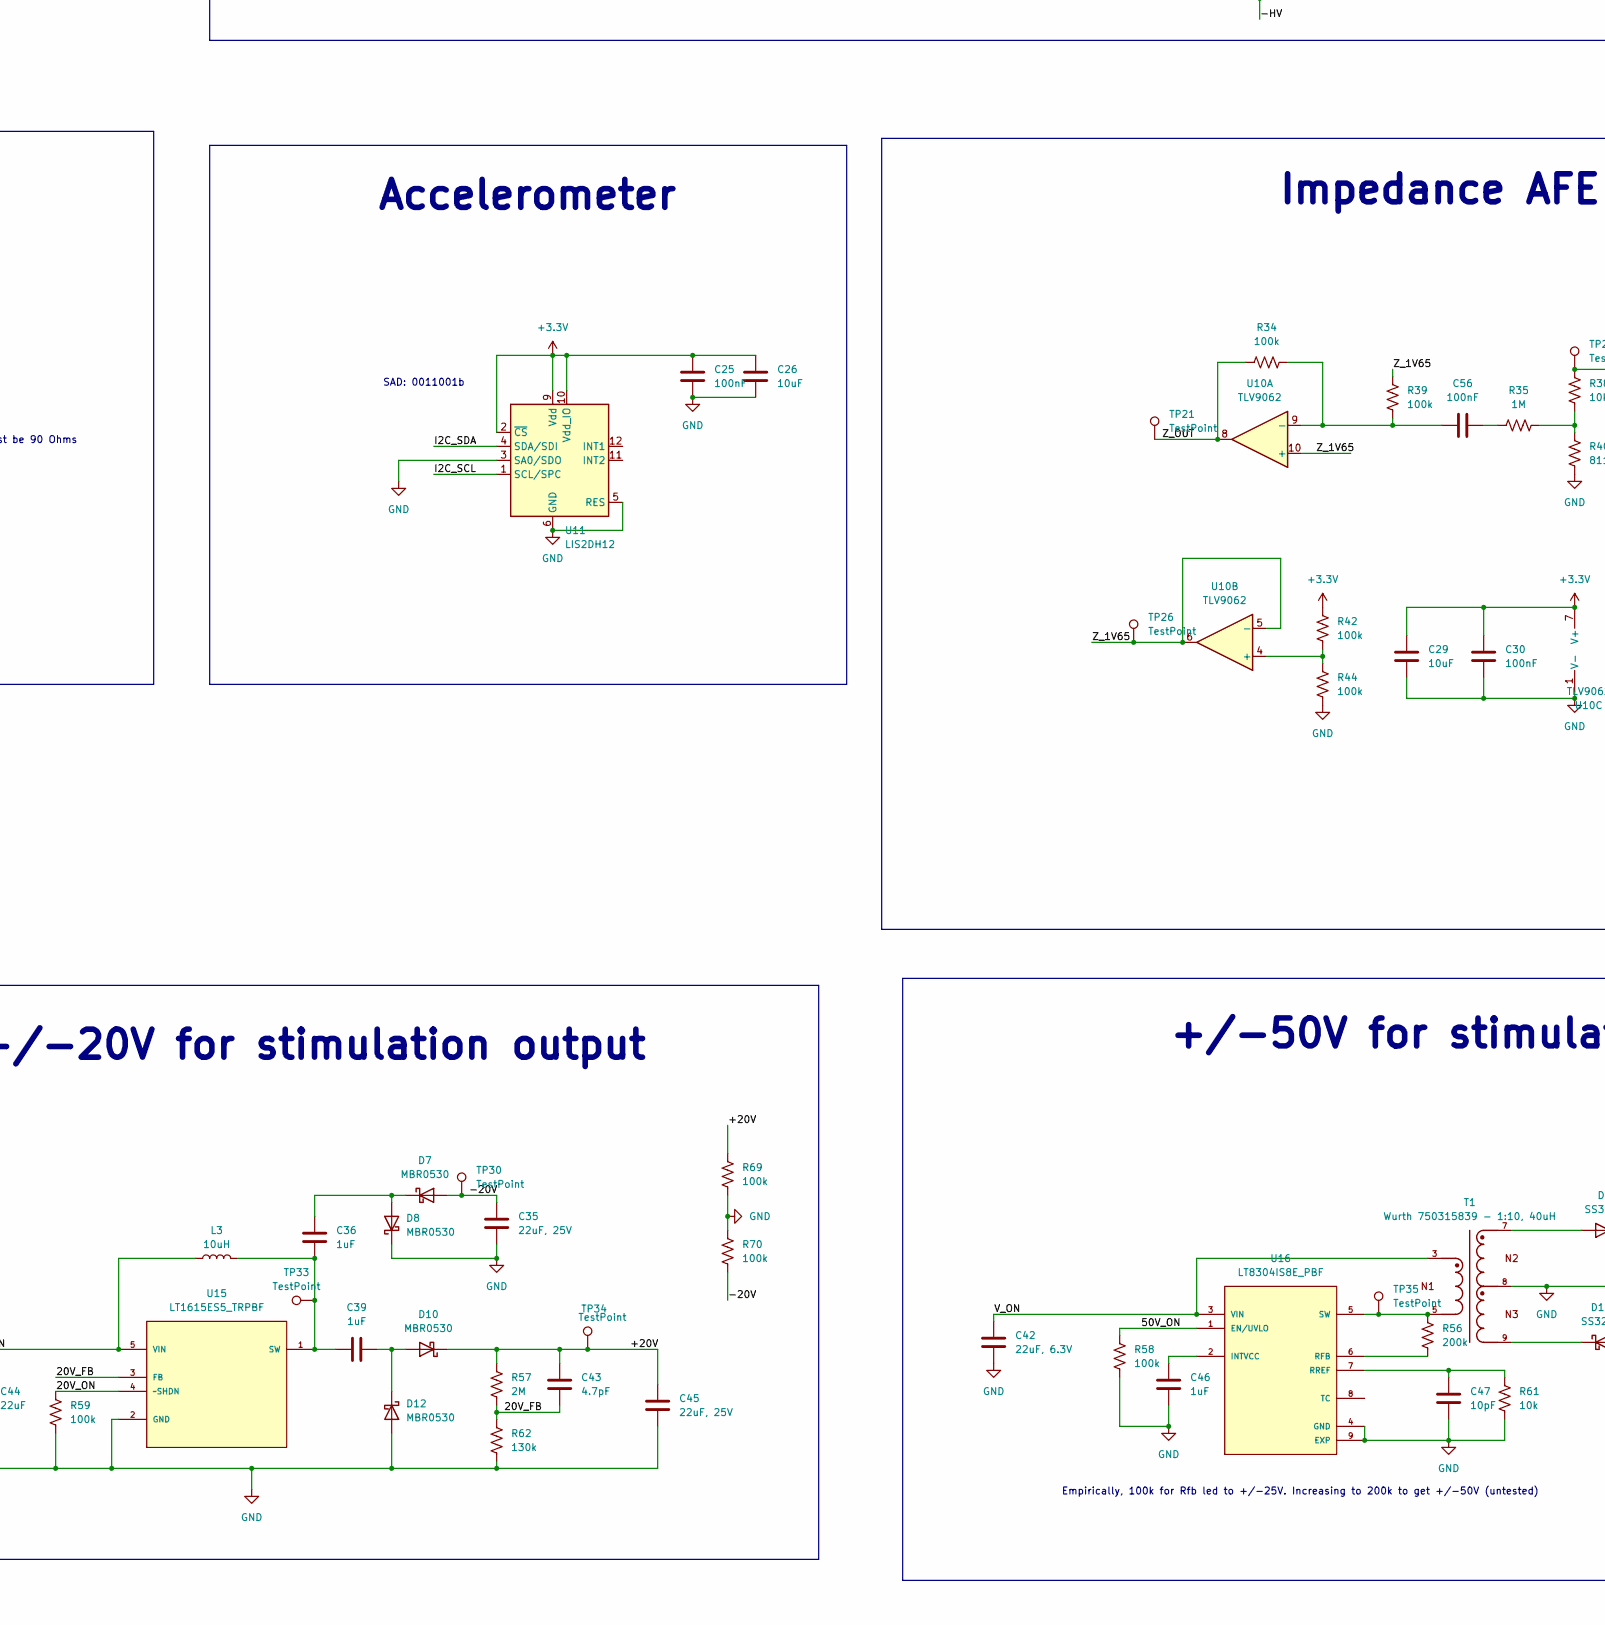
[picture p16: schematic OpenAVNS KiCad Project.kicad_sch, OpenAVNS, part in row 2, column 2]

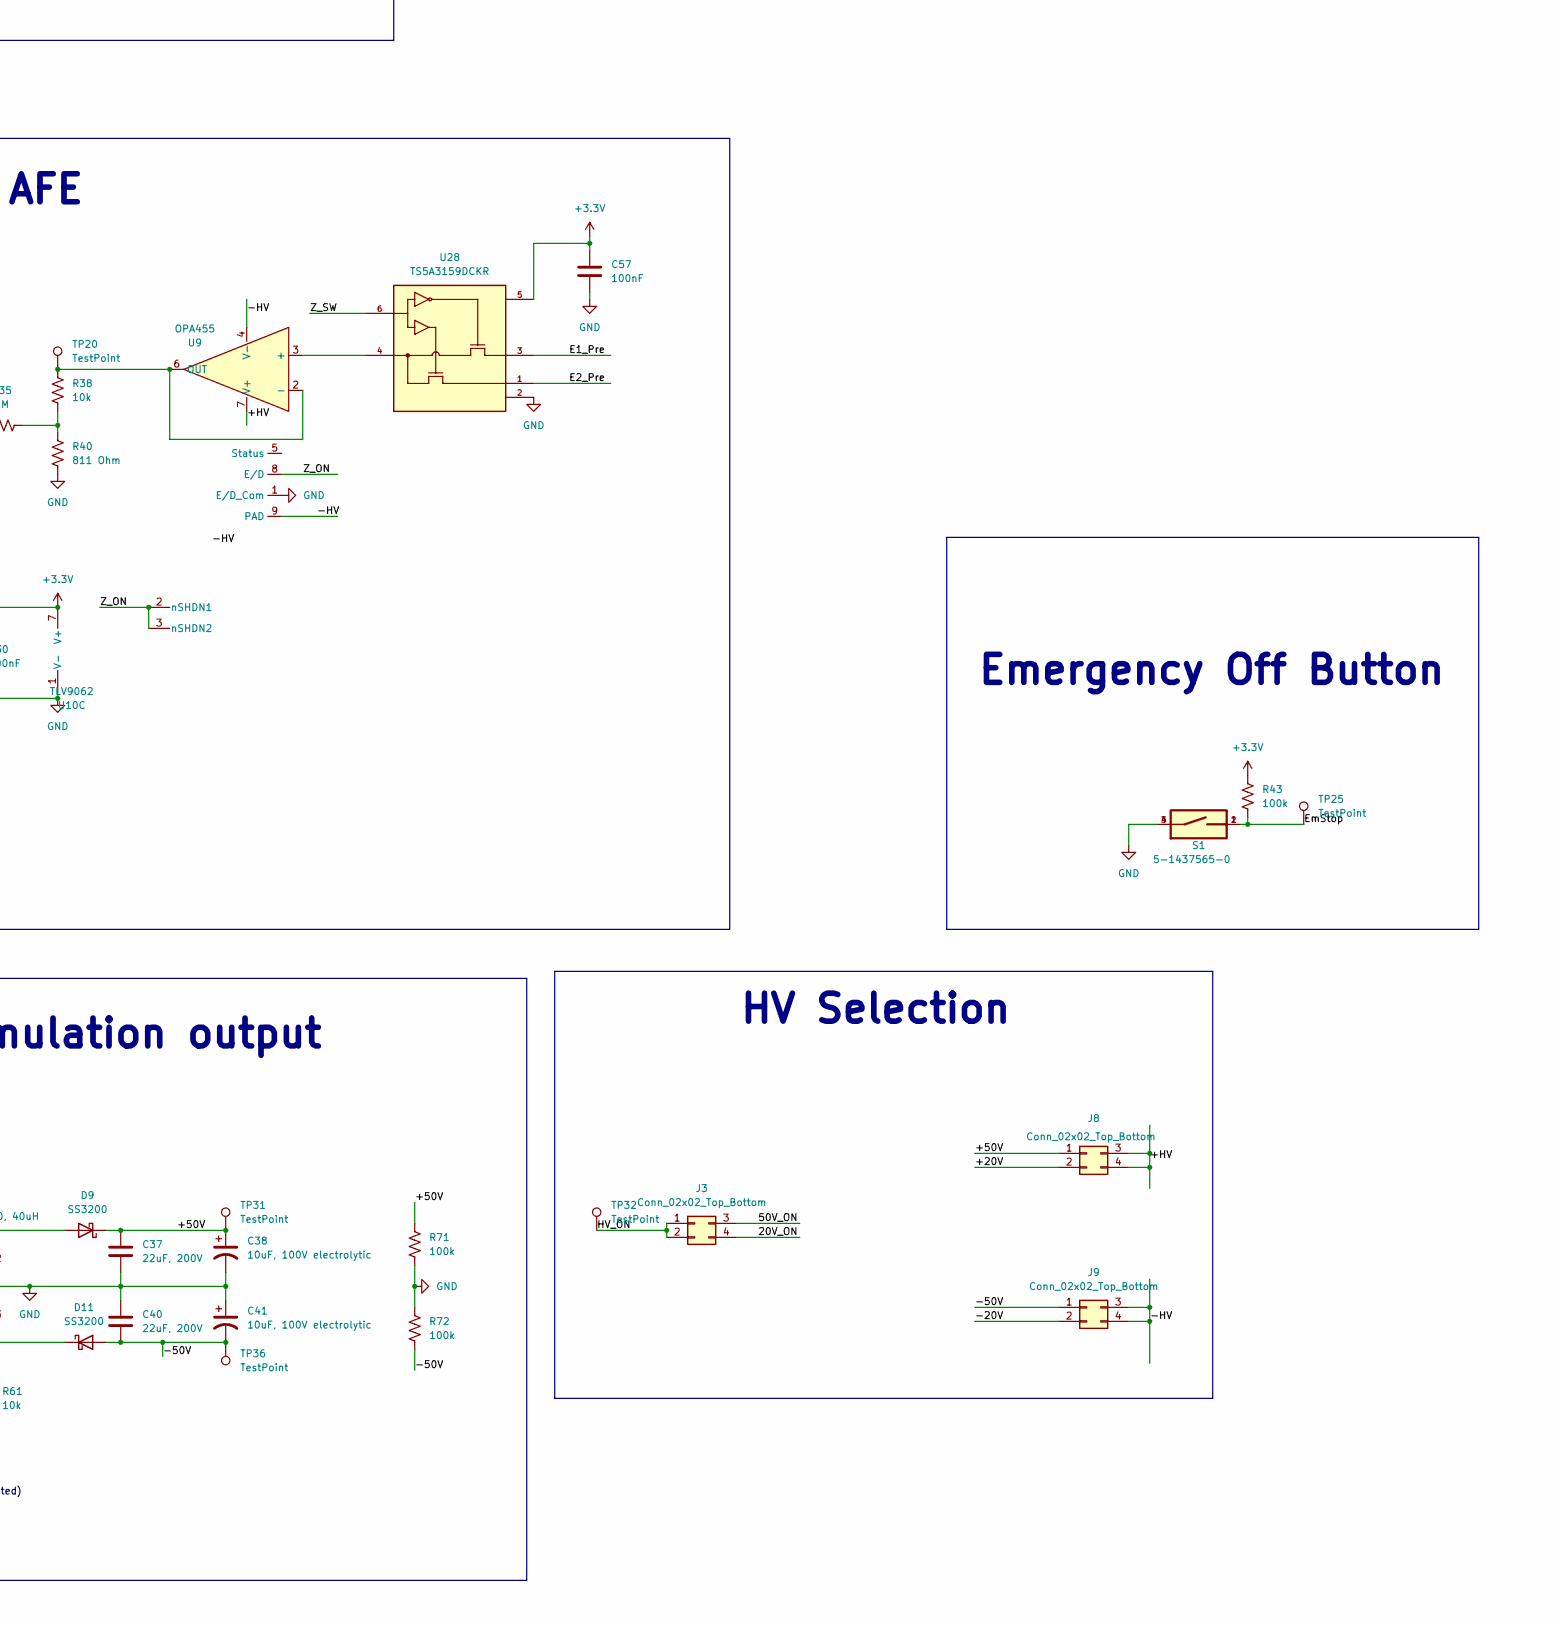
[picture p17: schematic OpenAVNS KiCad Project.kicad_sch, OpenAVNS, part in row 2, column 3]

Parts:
AT1: 2450AT43B100E; ANTENNA_2450AT43B100E; PARTREV N/A
C1, C46: 1uF; C_0603_1608Metric
C2, C7, C9, C19, C22, C24, C25, C30, C50, C51, C52, C53, C54, C55, C56, C57: 100nF; C_0402_1005Metric
C3: 820pF; C_0402_1005Metric
C4: 100pF; C_0402_1005Metric
C5, C6, C8: 4.7uF; C_0603_1608Metric
C10: 0.5pF; C_0402_1005Metric
C11: 0.8pF; C_0402_1005Metric
C12, C15, C16, C17, C23: 22uF; C_1210_3225Metric
C13, C20: 680pF; C_0402_1005Metric
C14, C21: 12pF; C_0402_1005Metric
C18, C26, C29: 10uF; C_0603_1608Metric
C31, C33: 0.1uF; C_0603_1608Metric
C32: 10uF; C_0805_2012Metric
C34, C44: 22uF; C_0805_2012Metric
C35, C45: 22uF, 25V; C_1210_3225Metric
C36, C39: 1uF; C_0805_2012Metric
C37, C40: 22uF, 200V; C_1210_3225Metric
C38, C41: 10uF, 100V electrolytic; CP_Radial_D6.3mm_P2.50mm
C42: 22uF, 6.3V; C_0805_2012Metric
C43: 4.7pF; C_0805_2012Metric
C47: 10pF; C_0603_1608Metric
C48, C49: 4.7uF; C_0805_2012Metric
D1, D2: SMAJ54CA; D_SMA
D3: PESD5V0L1UL; D_SOD-882
D5: SP0502BAHT; SOT-23
D7, D8, D10, D12: MBR0530; D_SOD-123
D9, D11: SS3200; D_SMA
D13: LED Yellow; LED_0402_1005Metric
D14: LED Green; LED_0402_1005Metric
H1, H2, H3, H4: MountingHole; MountingHole_3.2mm_M3_DIN965
J1: Conn_ARM_JTAG_SWD_10; PinHeader_2x05_P1.27mm_Vertical_SMD
J2: AudioPlug3; Jack_3.5mm_CUI_SJ-3523-SMT_Horizontal
J3, J8, J9: Conn_02x02_Top_Bottom; PinSocket_2x02_P2.54mm_Vertical
J4: Conn_01x02_Pin; PinHeader_1x02_P2.00mm_Vertical
J5: Conn_01x03_Pin; PinHeader_1x03_P2.54mm_Vertical
J6: Conn_01x01_Pin; PinHeader_1x01_P1.00mm_Horizontal
J7: 2171790001; MOLEX_2171790001; PARTREV A1
L1: 4.7nH, 5%; L_0402_1005Metric
L2: 4.7uH, 1.2A; L_1008_2520Metric_Pad1.43x2.20mm_HandSolder
L3: 10uH; L_7.3x7.3_H3.5
L4: 2.7nH, 5%; L_0402_1005Metric
L5: 1.8nH, 5%; L_0402_1005Metric
Q1, Q5: BCV62; SOT-143
Q2, Q6: BC847; SOT-23
Q3, Q7: BC857; SOT-23
Q4, Q8: BCV61; SOT-143
R1, R15, R19, R32: 1k; C_0805_2012Metric
R2, R16, R20, R33: 150 Ohm; C_0805_2012Metric
R3, R5, R8, R10, R22, R24, R29, R31: 100 Ohm; C_0402_1005Metric
R4, R9, R11, R14, R23, R30: 1M; C_0402_1005Metric
R6, R7, R27, R28: 4.4k; C_0805_2012Metric
R12, R13: 4.7k; R_0402_1005Metric
R17, R18, R49, R52, R53, R54: 100k; C_0402_1005Metric
R21, R34, R39, R42, R43, R44, R58, R59, R64, R67, R68: 100k; R_0402_1005Metric
R25, R26: 33 Ohm; R_0402_1005Metric
R35: 1M; R_0402_1005Metric
R36, R37: 5.1k; R_0402_1005Metric
R38: 10k; R_1206_3216Metric
R40: 811 Ohm; R_1206_3216Metric
R47: 2M; R_0402_1005Metric
R48: 1.2M; R_0402_1005Metric
R50, R51: 220k; R_0402_1005Metric
R55, R60, R73, R74: 500 Ohm; C_0402_1005Metric
R56: 200k; R_0805_2012Metric_Pad1.20x1.40mm_HandSolder
R57: 2M; R_0603_1608Metric
R61: 10k; R_0805_2012Metric_Pad1.20x1.40mm_HandSolder
R62: 130k; R_0603_1608Metric
R63: 330; R_0402_1005Metric
R65: 1k; R_0402_1005Metric
R66: 2k; R_0402_1005Metric
R69, R70, R71, R72: 100k; R_0805_2012Metric_Pad1.20x1.40mm_HandSolder
S1: 5-1437565-0; SW_SPST_PTS647_Sx38; PARTREV V
SW1: SW_SPDT; SW_SPDT_CK_JS102011SAQN
T1: Wurth 750315839 - 1:10, 40uH; WE-FLYLT_EP13_5465
TP1, TP2, TP3, TP4, TP5, TP6, TP7, TP8, TP9, TP10, TP11, TP12, TP13, TP14, TP15, TP16, TP17, TP18, TP19, TP20, TP21, TP25, TP26, TP28, TP29, TP30, TP31, TP32, TP33, TP34, TP35, TP36, TP37, TP38, TP39: TestPoint; TestPoint_Pad_D2.0mm
U2: TLV9004xRUCR; Texas_S-PX2QFN-14
U3, U7: MCP4725xxx-xCH; SOT-23-6
U5: nRF52840; Nordic_AQFN-73-1EP_7x7mm_P0.5mm
U9: OPA455; TI_SO-PowerPAD-8_ThermalVias
U10: TLV9062; QFN50P200X150X40-10N
U11: LIS2DH12; LGA-12_2x2mm_P0.5mm
U14: TPS61200DRC; Texas_S-PVSON-N10_ThermalVias
U15: LT1615ES5_TRPBF; SOT95P280X145-5N; MPN LT1615ES5#PBF
U16: LT8304IS8E_PBF; SOIC127P599X175-9N; PARTREV LT0217_REV_A
U17: MCP73831-2-OT; SOT-23-5
U18, U19, U20, U21, U22, U23, U24, U25, U26, U27, U28: TS5A3159DCKR; SOT65P210X110-6N; PARTREV D
Y1: 32MHz - X322532MOB4SI; Crystal_SMD_3225-4Pin_3.2x2.5mm

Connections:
+3.3V: C2.1, C5.1, C9.1, C18.1, C19.1, C22.1, C24.1, C25.1, C26.1, C29.1, C30.1, C34.1, C50.1, C51.1, C52.1, C53.1, C54.1, C55.1, C57.1, J1.1 (VTref), R7.2, R9.2, R12.2, R13.2, R28.2, R30.2, R42.2, R43.1, R48.1, TP28.1 (1_1), U2.3 (V+), U3.3 (VDD), U5.A22 (VDD), U5.AD14 (VDD), U5.AD23 (VDD), U5.B1 (VDD), U5.W1 (VDD), U5.Y2 (VDDH), U7.3 (VDD), U7.6 (A0), U10.7 (V+), U11.2 (~CS), U11.9 (Vdd), U11.10 (Vdd_IO), U14.2 (VOUT), U18.5, U19.5, U20.5, U21.5, U22.5, U23.5, U24.5, U25.5, U26.5, U27.5, U28.5
/20V_FB: C43.2, R57.1, R62.2, U15.3 (FB)
/20V_ON: J3.4, R59.2, U15.4 (~SHDN)
/50V_ON: J3.3, R58.2, U16.1 (EN/UVLO)
/+20V: C43.1, C45.1, D10.1 (K), J8.2, R57.2, R69.2, TP34.1 (1_1)
/+50V: C37.1, C38.1, D9.1 (K), J8.1, R71.2, TP31.1 (1_1)
/+HV: C15.1, J8.3, J8.4, R1.2, R2.2, R19.2, R20.2, U9.7 (V+)
/-20V: C35.1, D7.2 (A), J9.2, R70.1, TP30.1 (1_1)
/-50V: C40.2, C41.2, D11.2 (A), J9.1, R72.1, TP36.1 (1_1)
/-HV: C16.1, J9.3, J9.4, R15.1, R16.1, R32.1, R33.1, U9.4 (V-), U9.9 (PAD)
/Batt_Measure: R67.1, R68.2, U5.H2 (P0.27)
/C1A_ON: R11.2, U5.AD10 (P0.15), U18.6
/C1A_Out_Sw: R49.2, U5.Y23 (P1.01), U25.6
/C1C_ON: R14.2, U5.AC11 (P0.16), U19.6
/C1C_Out_Sw: R52.2, U5.W24 (P1.02), U24.6
/C1_Anodic: Q1.2 (C1), TP1.1 (1_1), U25.4
/C1_Cathodic: Q4.2 (C1), TP6.1 (1_1), U24.4
/C1_Out: U24.1, U25.1, U26.3
/C2A_ON: R17.2, U5.AD12 (P0.17), U20.6
/C2A_Out_Sw: R53.2, U5.V23 (P1.03), U23.6
/C2C_ON: R18.2, U5.AC15 (P0.19), U21.6
/C2C_Out_Sw: R54.2, U5.U24 (P1.04), U22.6
/C2_Anodic: Q5.2 (C1), TP10.1 (1_1), U23.4
/C2_Cathodic: Q8.2 (C1), TP19.1, U22.4
/C2_Out: U22.1, U23.1, U27.3
/E1: C12.2, J2.T, J5.1, TP5.1 (1_1)
/E1_GND_SW: U5.T23 (P1.05), U26.6
/E1_Pre: C12.1, C13.1, D1.2 (A2), U26.4, U28.3
/E2: C17.2, J2.R, J5.2, TP7.1 (1_1)
/E2_GND_SW: U5.R24 (P1.06), U27.6
/E2_Pre: C17.1, C20.1, D2.2 (A2), U27.4, U28.1
/EmStop: R43.2, S1.1, S1.2, TP25.1 (1_1), U5.AC21 (P0.25)
/Ground_Electrode: C23.2, J2.S, J5.3, R21.1, TP9.1 (1_1)
/HV_CLK: U5.AD20 (P0.24)
/HV_ON: J3.1, J3.2, TP32.1 (1_1), U5.AC19 (P0.23)
/I2C_SCL: R13.1, U3.5 (SCL), U5.AC9 (P0.14), U7.5 (SCL), U11.1 (SCL/SPC)
/I2C_SDA: R12.1, U3.4 (SDA), U5.AD8 (P0.13), U7.4 (SDA), U11.4 (SDA/SDI)
/MCU_D+: R26.2, U5.AD6 (D+)
/MCU_D-: R25.2, U5.AD4 (D-)
/RF_ANT: C10.2, L1.1, L4.2, L5.2
/RF_MCU: C11.2, L1.2, U5.H23 (ANT)
/SWO: J1.6 (SWO/TDO), TP14.1 (1_1), U5.AC17 (P0.21)
/USB_D+: D5.1 (K), J7.A6 (DP1), J7.B6 (DP2), R26.1
/USB_D-: D5.2 (K), J7.A7 (DN1), J7.B7 (DN2), R25.1
/VBAT: C49.1, J4.1, R67.2, SW1.1 (A), TP37.1 (1_1), U17.3 (V_{BAT})
/V_ON: C31.1, C32.1, C42.1, C44.1, D14.2 (A), L2.1, L3.1, R47.1, SW1.2 (B), T1.3, TP38.1 (1_1), U14.5 (VIN), U14.6 (EN), U14.8 (PS), U15.5 (VIN), U16.3 (VIN)
/V_USB: C6.1, C48.1, D3.1 (K), D13.2 (A), J7.A4B9 (VBUS1), J7.B4A9 (VBUS2), TP39.1 (1_1), U5.AD2 (VBUS), U17.4 (V_{DD})
/Z_1V65: R39.2, TP26.1 (1_1), U10.5 (-), U10.6, U10.10 (+)
/Z_ON: U5.G1 (P0.26), U9.8 (E/D), U10.2 (nSHDN1), U10.3 (nSHDN2)
/Z_OUT: R34.1, TP21.1 (1_1), U5.A12 (AIN0/P0.02), U10.8
/Z_SW: U5.B13 (AIN1/P0.03), U28.6
GND: C1.2, C2.2, C3.2, C4.2, C5.2, C6.2, C7.2, C8.2, C9.2, C10.1, C11.1, C13.2, C14.1, C15.2, C16.2, C18.2, C19.2, C20.2, C21.2, C22.2, C23.1, C24.2, C25.2, C26.2, C29.2, C30.2, C32.2, C33.2, C34.2, C35.2, C37.2, C38.2, C40.1, C41.1, C42.2, C44.2, C45.2, C46.2, C47.2, C48.2, C49.2, C50.2, C51.2, C52.2, C53.2, C54.2, C55.2, C57.2, D1.1 (A1), D2.1 (A1), D3.2 (A), D5.3 (A), D8.1 (K), D12.2 (A), J1.3 (GND), J1.5 (GND), J1.9 (GNDDetect), J4.2, J7.A1B12 (GND1), J7.B1A12 (GND2), J7.SH1 (SHIELD1), J7.SH2 (SHIELD2), J7.SH3 (SHIELD3), J7.SH4 (SHIELD4), L5.1, R4.1, R6.1, R11.1, R14.1, R17.1, R18.1, R21.2, R23.1, R27.1, R36.2, R37.2, R40.2, R44.1, R49.1, R50.2, R51.2, R52.1, R53.1, R54.1, R55.1, R58.1, R59.1, R60.1, R61.1, R62.1, R64.1, R65.1, R66.2, R68.1, R69.1, R70.2, R71.1, R72.2, R73.1, R74.1, S1.3, S1.4, T1.8, TP8.1 (1_1), TP17.1 (1_1), U2.10 (V-), U3.2 (VSS), U3.6 (A0), U5.B7 (VSS), U5.EP (VSS), U5.F23 (VSS_PA), U7.2 (VSS), U9.1 (E/D_Com), U10.1 (V-), U11.3 (SA0/SDO), U11.5 (RES), U11.6 (GND), U11.7 (GND), U11.8 (GND), U14.4 (PGND), U14.9 (GND), U14.11 (PAD), U15.2 (GND), U16.4 (GND), U16.9 (EXP), U17.2 (V_{SS}), U18.2, U19.2, U20.2, U21.2, U22.2, U23.2, U24.2, U25.2, U26.1, U26.2, U27.1, U27.2, U28.2, Y1.2, Y1.4
unnamed: AT1.1, L4.1
unnamed: C56.2, R35.1
unnamed: C36.1, D7.1 (K), D8.2 (A)
unnamed: D9.2 (A), T1.7
unnamed: C39.2, D10.2 (A), D12.1 (K)
unnamed: D11.1 (K), T1.9
unnamed: D13.1 (K), R63.2
unnamed: D14.1 (K), R65.2
unnamed: J1.4 (SWCLK/TCK), TP12.1 (1_1), U5.AA24 (SWDCLK)
unnamed: J1.2 (SWDIO/TMS), TP13.1 (1_1), U5.AC24 (SWDIO)
unnamed: J1.10 (~RESET), TP11.1 (1_1), U5.AC13 (P0.18/~RESET)
unnamed: J6.1 (Pin_1_1), U5.B19 (P1.11)
unnamed: J7.A5 (CC1), R37.1
unnamed: J7.B5 (CC2), R36.1
unnamed: Q1.1 (C2), Q2.3 (C)
unnamed: Q1.3 (E1), R2.1
unnamed: Q1.4 (E2), R1.1
unnamed: Q2.1 (B), R3.1
unnamed: Q2.2 (E), R5.2, R6.2, TP2.1 (1_1)
unnamed: Q3.1 (B), R10.2
unnamed: Q3.3 (C), Q4.1 (C2)
unnamed: Q3.2 (E), R7.1, R8.2, TP4.1 (1_1)
unnamed: Q4.3 (E1), R16.2
unnamed: Q4.4 (E2), R15.2
unnamed: Q5.1 (C2), Q6.3 (C)
unnamed: Q5.3 (E1), R20.1
unnamed: Q5.4 (E2), R19.1
unnamed: Q6.1 (B), R22.1
unnamed: Q6.2 (E), R24.2, R27.2, TP15.1 (1_1)
unnamed: Q7.1 (B), R31.2
unnamed: Q7.3 (C), Q8.1 (C2)
unnamed: Q7.2 (E), R28.1, R29.2, TP18.1 (1_1)
unnamed: Q8.3 (E1), R33.2
unnamed: Q8.4 (E2), R32.2
unnamed: R3.2, U2.14
unnamed: R10.1, U2.6
unnamed: R22.2, U2.7
unnamed: R31.1, U2.13
unnamed: R35.2, R38.2, R40.1
unnamed: R55.2, U22.3
unnamed: R60.2, U23.3
unnamed: R73.2, U24.3
unnamed: R74.2, U25.3
unnamed: R64.2, SW1.3 (C)
unnamed: R4.2, U2.2 (+), U18.1
unnamed: R5.1, U2.1 (-)
unnamed: R9.1, U2.4 (+), U19.1
unnamed: R8.1, U2.5 (-)
unnamed: R23.2, U2.9 (+), U20.1
unnamed: R24.1, U2.8 (-)
unnamed: R30.1, U2.11 (+), U21.1
unnamed: R29.1, U2.12 (-)
unnamed: TP3.1 (1_1), U3.1 (VOUT), U18.4, U19.4
unnamed: C7.1, U5.C1 (DEC1)
unnamed: C4.1, U5.D23 (DEC3)
unnamed: C1.1, U5.B5 (DEC4), U5.E24 (DEC6)
unnamed: C3.1, U5.N24 (DEC5)
unnamed: C8.1, U5.AC5 (DECUSB)
unnamed: C14.2, U5.B24 (XC1), Y1.3
unnamed: C21.1, U5.A23 (XC2), Y1.1
unnamed: TP16.1 (1_1), U7.1 (VOUT), U20.4, U21.4
unnamed: U9.3 (+), U28.4
unnamed: R38.1, TP20.1 (1_1), U9.2 (-), U9.6 (OUT)
unnamed: C56.1, R34.2, R39.1, U10.9 (-)
unnamed: R42.1, R44.2, U10.4 (+)
unnamed: R48.2, R51.1, TP29.1 (1_1), U14.10 (FB)
unnamed: L2.2, U14.3 (L)
unnamed: C31.2, R47.2, R50.1, U14.7 (UVLO)
unnamed: C33.1, U14.1 (VAUX)
unnamed: C36.2, C39.1, L3.2, TP33.1 (1_1), U15.1 (SW)
unnamed: C46.1, U16.2 (INTVCC)
unnamed: R56.1, U16.6 (RFB)
unnamed: C47.1, R61.2, U16.7 (RREF)
unnamed: R56.2, T1.5, TP35.1 (1_1), U16.5 (SW)
unnamed: R66.1, U17.5 (PROG)
unnamed: R63.1, U17.1 (STAT)

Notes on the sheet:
3V3 Converter
SAD: 0011001b
MCU - nRF52840
HV Selection
Battery Charger
Anodic: at 3.3V output from DAC, I_out = 0.75mA
Config. 3 in nRF52840 manual (low power supply, USB on, NFC off, no external supplies)
Decoupling caps placed near the current mirrors
Impedance AFE
SMAJ22CA diode clamps output voltage at +/-22V Replace with SMAJ54CA if using 50V supply
SAD: 1100001b
Stimulation Output
Power Switch
Cathodic: at 0V output from DAC, I_out = 0.75mA
Battery Connector - JST
+/-50V for stimulation output
Electrodes
Current mirror amplifies 0.75mA input to 5mA output (6.67x)
+/-20V for stimulation output
DC block cap time constant of ~0.2s (assuming 10k skin impedance)
Accelerometer
Both D+/D- pairs must be 90 ohms
Note: reference pin only, not power. 3V3 needs to be powered separately for programming
GPIO for triggering / multipurpose
D+ / D- differential pair must be 90 Ohms
Empirically, 100k for Rfb led to +/-25V. Increasing to 200k to get +/-50V (untested)
SAD: 1100000b
Emergency Off Button
RF_ANT and RF_MCU must both be 50 Ohms
USB-C Power and Data

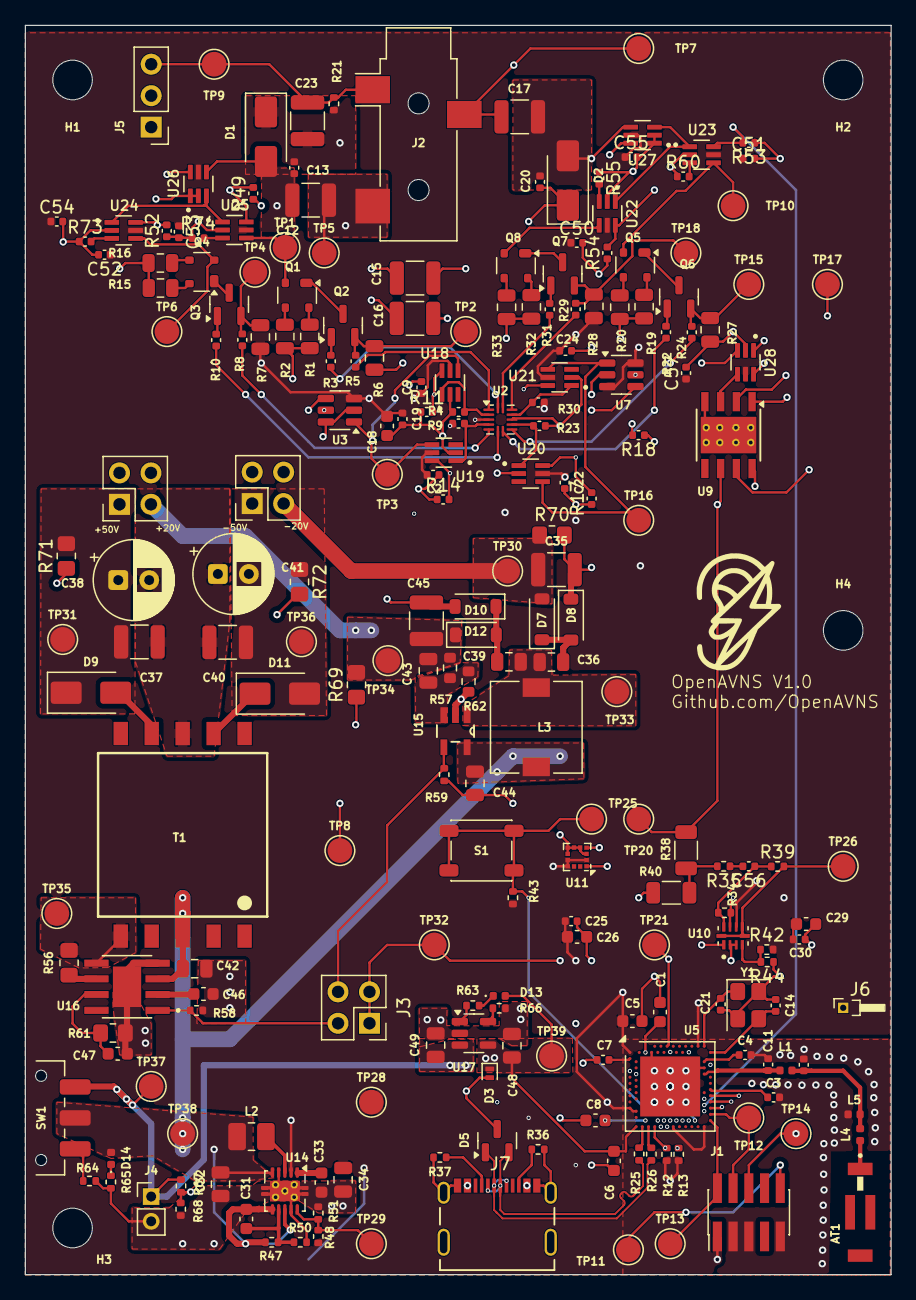
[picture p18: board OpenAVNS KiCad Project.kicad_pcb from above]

Board: 4 copper layers, 69.9 x 100.9 mm, 225 parts (0 on the bottom side), 127 nets.

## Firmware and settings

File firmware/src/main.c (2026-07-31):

#include <zephyr/kernel.h>
#include <zephyr/sys/printk.h>
#include <zephyr/device.h>
#include <zephyr/drivers/gpio.h>
#include <zephyr/drivers/i2c.h>
#include <zephyr/bluetooth/bluetooth.h>
#include <zephyr/shell/shell.h>
#include <zephyr/sys/atomic.h>
#include <zephyr/usb/usb_device.h>

/* ------------------------------------------------------------------ */
/* Square-wave generator                                               */
/* ------------------------------------------------------------------ */
/*
 * A dedicated thread toggles a GPIO pin at a user-specified half-period.
 * Thread priority is K_PRIO_PREEMPT(15), one step below the shell default
 * (K_PRIO_PREEMPT(14)), so the shell can always preempt it and "sq stop"
 * is processed promptly.
 *
 * Timing strategy:
 *   half_period < 1000 us  -> k_busy_wait()  (CPU spin, ~1 us accuracy)
 *   half_period >= 1000 us -> k_usleep()     (yields CPU, shell stays snappy)
 *
 * Commands:
 *   sq start <gpio_dev> <pin> <half_period_us>
 *   sq stop
 *   sq status
 */

static atomic_t          sq_running = ATOMIC_INIT(0);
static volatile uint32_t sq_half_us;
static const struct device *sq_dev;
static volatile gpio_pin_t  sq_pin;

#define SQ_STACK_SIZE 1024
#define SQ_PRIORITY   K_PRIO_PREEMPT(15)

static void sq_thread_fn(void *a, void *b, void *c)
{
	ARG_UNUSED(a); ARG_UNUSED(b); ARG_UNUSED(c);

	while (1) {
		if (!atomic_get(&sq_running)) {
			k_sleep(K_MSEC(10));
			continue;
		}

		gpio_pin_toggle(sq_dev, sq_pin);

		k_busy_wait(sq_half_us);
	}
}

K_THREAD_DEFINE(sq_tid, SQ_STACK_SIZE, sq_thread_fn,
		NULL, NULL, NULL, SQ_PRIORITY, 0, 0);

static int cmd_sq_start(const struct shell *sh, size_t argc, char **argv)
{
	const struct device *dev = shell_device_get_binding(argv[1]);

	if (!dev) {
		shell_error(sh, "Unknown device '%s'", argv[1]);
		return -ENODEV;
	}

	gpio_pin_t pin      = (gpio_pin_t)atoi(argv[2]);
	uint32_t   half_us  = (uint32_t)atoi(argv[3]);

	if (half_us == 0U) {
		shell_error(sh, "half-period must be >= 1 us");
		return -EINVAL;
	}

	int ret = gpio_pin_configure(dev, pin, GPIO_OUTPUT_LOW);

	if (ret < 0) {
		shell_error(sh, "gpio_pin_configure failed: %d", ret);
		return ret;
	}

	/* Write params before raising the running flag */
	sq_dev     = dev;
	sq_pin     = pin;
	sq_half_us = half_us;
	atomic_set(&sq_running, 1);

	shell_print(sh, "Started: %s pin %u  half-period %u us  (~%u Hz)",
		    argv[1], pin, half_us, 500000U / half_us);
	return 0;
}

static int cmd_sq_stop(const struct shell *sh, size_t argc, char **argv)
{
	atomic_set(&sq_running, 0);
	if (sq_dev) {
		gpio_pin_set(sq_dev, sq_pin, 0);
	}
	shell_print(sh, "Stopped");
	return 0;
}

static int cmd_sq_status(const struct shell *sh, size_t argc, char **argv)
{
	if (!atomic_get(&sq_running) || !sq_dev) {
		shell_print(sh, "Stopped");
		return 0;
	}
	uint32_t half = sq_half_us;

	shell_print(sh, "Running: %s pin %u  half-period %u us  (~%u Hz)",
		    sq_dev->name, sq_pin, half, 500000U / half);
	return 0;
}

SHELL_STATIC_SUBCMD_SET_CREATE(sq_cmds,
	SHELL_CMD_ARG(start, NULL,
		"<gpio_dev> <pin> <half_period_us>\n"
		"  Toggle a pin symmetrically. Range: 1 us to 100000000 us.\n"
		"  Examples:\n"
		"    sq start gpio0 15 1        (~500 kHz, 1 us half-period)\n"
		"    sq start gpio0 15 500      (~1 kHz,   500 us half-period)\n"
		"    sq start gpio0 15 1000     (~500 Hz,  1 ms half-period)\n"
		"    sq start gpio0 15 100000   (~5 Hz,    100 ms half-period)",
		cmd_sq_start, 4, 0),
	SHELL_CMD_ARG(stop,   NULL, "Stop toggling and drive pin LOW",
		cmd_sq_stop,   1, 0),
	SHELL_CMD_ARG(status, NULL, "Show current generator state",
		cmd_sq_status, 1, 0),
	SHELL_SUBCMD_SET_END
);

SHELL_CMD_REGISTER(sq, &sq_cmds, "Square-wave generator on any GPIO pin", NULL);

/* ------------------------------------------------------------------ */
/* Stim command                                                        */
/* ------------------------------------------------------------------ */
/*
 * Sets a channel's MCP4725 DAC to the requested voltage, then toggles
 * the channel's two GPIO pins in strict antiphase (one HIGH while the
 * other is LOW) at the requested frequency.
 *
 * gpio_port_set_masked_raw() writes both pins in a single register
 * access so they switch simultaneously.
 *
 * Commands:
 *   stim start <channel 1|2> <voltage_mv> <freq_hz>
 *   stim stop
 *
 * Channel pin mapping:
 *   ch1 — DAC 0x62, P0.15 (+), P0.16 (-)
 *   ch2 — DAC 0x63, P0.17 (+), P0.19 (-)
 */

static const struct device *const stim_i2c = DEVICE_DT_GET(DT_NODELABEL(i2c0));
static const struct device *const stim_gpio = DEVICE_DT_GET(DT_NODELABEL(gpio0));

static const uint8_t   stim_dac_addr[2]  = { 0x62, 0x63 };
static const gpio_pin_t stim_pin_pos[2]  = { 15, 17 };
static const gpio_pin_t stim_pin_neg[2]  = { 16, 19 };

static atomic_t          stim_running = ATOMIC_INIT(0);
static volatile uint32_t stim_half_us;
static volatile gpio_pin_t stim_pos;
static volatile gpio_pin_t stim_neg;

#define STIM_STACK_SIZE 1024
#define STIM_PRIORITY   K_PRIO_PREEMPT(15)

static void stim_set_dac(uint8_t addr, uint16_t d)
{
	uint8_t buf[2] = { (d >> 8) & 0x0F, d & 0xFF };

	i2c_write(stim_i2c, buf, sizeof(buf), addr);
}

static void stim_thread_fn(void *a, void *b, void *c)
{
	ARG_UNUSED(a); ARG_UNUSED(b); ARG_UNUSED(c);

	while (1) {
		if (!atomic_get(&stim_running)) {
			k_sleep(K_MSEC(10));
			continue;
		}

		gpio_pin_t pos = stim_pos;
		gpio_pin_t neg = stim_neg;
		gpio_port_pins_t mask = BIT(pos) | BIT(neg);
		uint32_t half = stim_half_us;

		/* Phase A: pos HIGH, neg LOW */
		gpio_port_set_masked_raw(stim_gpio, mask, BIT(pos));
		k_busy_wait(half);

		if (!atomic_get(&stim_running)) {
			gpio_port_set_masked_raw(stim_gpio, mask, 0);
			continue;
		}

		/* Phase B: pos LOW, neg HIGH */
		gpio_port_set_masked_raw(stim_gpio, mask, BIT(neg));
		k_busy_wait(half);
	}
}

K_THREAD_DEFINE(stim_tid, STIM_STACK_SIZE, stim_thread_fn,
		NULL, NULL, NULL, STIM_PRIORITY, 0, 0);

static int cmd_stim_start(const struct shell *sh, size_t argc, char **argv)
{
	int ch = atoi(argv[1]);

	if (ch < 1 || ch > 2) {
		shell_error(sh, "channel must be 1 or 2");
		return -EINVAL;
	}

	uint32_t voltage_mv = (uint32_t)atoi(argv[2]);

	if (voltage_mv > 3300U) {
		shell_error(sh, "voltage_mv must be 0-3300");
		return -EINVAL;
	}

	uint32_t freq_hz = (uint32_t)atoi(argv[3]);

	if (freq_hz == 0U) {
		shell_error(sh, "freq_hz must be >= 1");
		return -EINVAL;
	}

	uint32_t half_us = 500000U / freq_hz;

	if (half_us == 0U) {
		shell_error(sh, "frequency too high");
		return -EINVAL;
	}

	int idx = ch - 1;

	/* Stop any running stim before reconfiguring */
	atomic_set(&stim_running, 0);
	k_sleep(K_MSEC(20));

	/* Enable HV rail before configuring outputs */
	gpio_pin_configure(stim_gpio, 23, GPIO_OUTPUT_HIGH);

	/* Configure pins as outputs, initially LOW */
	gpio_pin_configure(stim_gpio, stim_pin_pos[idx], GPIO_OUTPUT_LOW);
	gpio_pin_configure(stim_gpio, stim_pin_neg[idx], GPIO_OUTPUT_LOW);

	/* Set DAC */
	uint16_t dac_val = (uint16_t)(voltage_mv * 4096U / 3300U);

	stim_set_dac(stim_dac_addr[idx], dac_val);

	/* Publish params then start thread */
	stim_pos     = stim_pin_pos[idx];
	stim_neg     = stim_pin_neg[idx];
	stim_half_us = half_us;
	atomic_set(&stim_running, 1);

	shell_print(sh, "Stim ch%d: %u mV  %u Hz  (half-period %u us)",
		    ch, voltage_mv, freq_hz, half_us);
	return 0;
}

static int cmd_stim_stop(const struct shell *sh, size_t argc, char **argv)
{
	atomic_set(&stim_running, 0);

	/* Drive all channel pins LOW */
	for (int i = 0; i < 2; i++) {
		gpio_port_set_masked_raw(stim_gpio,
					 BIT(stim_pin_pos[i]) | BIT(stim_pin_neg[i]),
					 0);
	}

	/* Zero both DACs */
	stim_set_dac(0x62, 0);
	stim_set_dac(0x63, 0);

	/* Disable HV rail last */
	gpio_pin_set(stim_gpio, 23, 0);

	shell_print(sh, "Stopped. Pins LOW, DACs zeroed, HV disabled.");
	return 0;
}

SHELL_STATIC_SUBCMD_SET_CREATE(stim_cmds,
	SHELL_CMD_ARG(start, NULL,
		"<channel 1|2> <voltage_mv> <freq_hz>\n"
		"  Set DAC and toggle pos/neg pins in antiphase at freq_hz.\n"
		"  ch1: DAC 0x62, P0.15(+) P0.16(-)    ch2: DAC 0x63, P0.17(+) P0.19(-)\n"
		"  Examples:\n"
		"    stim start 1 1000 10    (ch1, 1.0V, 10 Hz)\n"
		"    stim start 2 2500 100   (ch2, 2.5V, 100 Hz)",
		cmd_stim_start, 4, 0),
	SHELL_CMD_ARG(stop, NULL,
		"Stop stimulation, drive all pins LOW, zero both DACs",
		cmd_stim_stop, 1, 0),
	SHELL_SUBCMD_SET_END
);

SHELL_CMD_REGISTER(stim, &stim_cmds, "Stimulation output control", NULL);

/* ------------------------------------------------------------------ */
/* BLE advertisement                                                   */
/* ------------------------------------------------------------------ */
/*
 * Non-connectable advertisement for antenna testing.
 * Open nRF Connect → Scanner and look for CONFIG_BT_DEVICE_NAME.
 * RSSI at ~1m should be roughly −50 to −70 dBm on a healthy antenna.
 *
 * Commands:
 *   ble start
 *   ble stop
 */

static const struct bt_data ble_ad[] = {
	BT_DATA_BYTES(BT_DATA_FLAGS, BT_LE_AD_NO_BREDR | BT_LE_AD_GENERAL),
};

static const struct bt_data ble_sd[] = {
	BT_DATA(BT_DATA_NAME_COMPLETE,
		CONFIG_BT_DEVICE_NAME,
		sizeof(CONFIG_BT_DEVICE_NAME) - 1),
};

static bool ble_initialized;

static int cmd_ble_start(const struct shell *sh, size_t argc, char **argv)
{
	int err;

	if (!ble_initialized) {
		err = bt_enable(NULL);
		if (err) {
			shell_error(sh, "bt_enable failed: %d", err);
			return err;
		}
		ble_initialized = true;
	}

	err = bt_le_adv_start(BT_LE_ADV_NCONN_IDENTITY,
			      ble_ad, ARRAY_SIZE(ble_ad),
			      ble_sd, ARRAY_SIZE(ble_sd));
	if (err && err != -EALREADY) {
		shell_error(sh, "bt_le_adv_start failed: %d", err);
		return err;
	}

	shell_print(sh, "Advertising as \"%s\" — open nRF Connect to see RSSI",
		    CONFIG_BT_DEVICE_NAME);
	return 0;
}

static int cmd_ble_stop(const struct shell *sh, size_t argc, char **argv)
{
	bt_le_adv_stop();
	shell_print(sh, "Advertising stopped");
	return 0;
}

SHELL_STATIC_SUBCMD_SET_CREATE(ble_cmds,
	SHELL_CMD_ARG(start, NULL, "Start BLE advertisement", cmd_ble_start, 1, 0),
	SHELL_CMD_ARG(stop,  NULL, "Stop BLE advertisement",  cmd_ble_stop,  1, 0),
	SHELL_SUBCMD_SET_END
);

SHELL_CMD_REGISTER(ble, &ble_cmds, "BLE advertisement for antenna testing", NULL);

/* ------------------------------------------------------------------ */
/* Main                                                                */
/* ------------------------------------------------------------------ */

int main(void)
{
	usb_enable(NULL);
	printk("nRF52840 bring-up shell ready\n");
	printk("Type 'help' for commands\n");
	return 0;
}

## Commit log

2025-09-02 Add schematic and supporting files for PCB
    First organizational-level upload of the KiCad project and files for OpenAVNS.
    [LT1615ES5_TRPBF.step, LT8304IS8E_PBF.step, OpenAVNS KiCad Project.kicad_pcb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]
2025-09-02 Added PDF of schematic
    [OpenAVNS KiCad Project.kicad_sch]
2025-09-05 Added 3D model
    [2450AT43B100E.step]
2025-09-05 Updated footprints in schematic
    [OpenAVNS KiCad Project.kicad_sch, TLV9062SIRUGR.step]
2025-09-06 Changed 50V converter config, eliminating op amp. Also changed some footprints (work in progress)
    [OpenAVNS KiCad Project.kicad_pcb, OpenAVNS KiCad Project.kicad_sch]
2025-09-09 Fixed some schematic parts, added test points and 3.5mm jack for output
    [OpenAVNS KiCad Project.kicad_pcb, OpenAVNS KiCad Project.kicad_sch]
2025-09-09 Updated PDF of schematic
2025-09-19 Updated 50V cap values and size
    [OpenAVNS KiCad Project.kicad_pcb, OpenAVNS KiCad Project.kicad_sch]
2025-09-20 Some lazy Saturday floorplanning on the layout
    [OpenAVNS KiCad Project.kicad_pcb, OpenAVNS KiCad Project.kicad_sch]
2025-09-26 Started doing proper layout
    [OpenAVNS KiCad Project.kicad_pcb, OpenAVNS KiCad Project.kicad_sch]
2025-10-25 First draft of layout, still has work to be done
    [OpenAVNS KiCad Project.kicad_pcb, OpenAVNS KiCad Project.kicad_sch]
2025-10-28 Added 3D model for transformer
    [OpenAVNS KiCad Project.kicad_pcb, PCB STEP file.step]
2025-10-29 Fixed 3D models
    [JS102011SAQN.STEP, OpenAVNS KiCad Project.kicad_pcb, PCB STEP file.step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]
2025-10-29 Added mounting holes
    [OpenAVNS KiCad Project.kicad_pcb, OpenAVNS KiCad Project.kicad_sch]
2025-11-10 Finished routing, working through DRC
    [OpenAVNS KiCad Project.kicad_pcb]
2025-11-14 Added GPIO pin for triggering or other multipurpose applications
    [OpenAVNS KiCad Project.kicad_pcb, OpenAVNS KiCad Project.kicad_sch]
2025-11-14 Generated new PDFs and STEP files
    [OpenAVNS KiCad Project.kicad_pcb, PCB STEP file.step]
2025-11-14 Deleted old schematic
2025-11-21 Fixed hole clearance DRC errors
    [OpenAVNS KiCad Project.kicad_pcb]
2025-12-16 Edited based on Maros advice, thanks
    [BOM JLCPCB.xlsx, BOM OpenAVNS KiCad Project.csv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]
2025-12-17 Updated USB connector and routing
    [2171790001.step, OpenAVNS KiCad Project.kicad_pcb, OpenAVNS KiCad Project.kicad_sch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]
2025-12-22 Replaced zero ohm resistors with headers
    [OpenAVNS KiCad Project.kicad_pcb, OpenAVNS KiCad Project.kicad_sch]
2025-12-31 Updated footprint of switches based on component availability
    [OpenAVNS KiCad Project.kicad_pcb, OpenAVNS KiCad Project.kicad_sch, TS5A3159DCKR.step]
2025-12-31 Updated U13 footprint
    [OpenAVNS KiCad Project.kicad_pcb, OpenAVNS KiCad Project.kicad_sch]
2025-12-31 Added electrode as PCB project, updated manufacturing files and taped out first version
    [BOM OpenAVNS KiCad Project.csv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]
2026-04-09 Reorganized schematic
    [OpenAVNS KiCad Project.kicad_sch]
2026-07-31 Updated PCBA design based on debugging results - untested, still needs more work and simulation
    [OpenAVNS KiCad Project.kicad_pcb, OpenAVNS KiCad Project.kicad_sch]
2026-07-31 Add .gitignore; untrack KiCad local-history repo, backup zips, and .DS_Store
    hardware/.history was accidentally committed as a broken submodule
    reference (no .gitmodules, no remote) and 79 timestamped backup zips
    from KiCad's autosave feature got swept in with it. None of these are
    design source, so they're removed from tracking (files remain on disk
    locally) and ignored going forward.
2026-07-31 Put BOM where it should be
    [BOM JLCPCB.xlsx]
2026-07-31 Routed schematic with new output switches, new impedance circuit
    [OpenAVNS KiCad Project.kicad_pcb, OpenAVNS KiCad Project.kicad_sch]
